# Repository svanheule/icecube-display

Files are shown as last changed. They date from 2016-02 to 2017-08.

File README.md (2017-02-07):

# IceCube LED display
This repository contains design documents and firmware source code for a number of LED displays
designed to show IceCube event data.

## Integration in Steamshovel
A Steamshovel artist was written using pyusb to enable remote rendering.
This allows people already familiar with the IceCube offline event viewer to also be quickly
able to get a new LED display up and running.

## Firmware
The display firmware is written using bare-metal C to provide close integration with the hardware.
Writing a new firmware implementation can take up quite some time, so try to re-use an existing
design if possible. All source code is contained in the `firmware` directory.

Source code documentation containing guidelines for new display and a short description of
existing displays can be compiled using Doxygen:
```{.sh}
$ doxygen Doxyfile
```

A copy of the documentation may be found at
http://icecube.wisc.edu/~svanheule/icecube-display.

Builds of the microcontroller firmwares can be found at
http://icecube.wisc.edu/~svanheule/images.
These builds can be used to upgrade existing devices, or provide a starting point for uploading
the device EEPROM when using a new device.

## Hardware
The `hardware` directory contains design documents for the displays.
This includes both mechanical documents for the display construction, as well as possible
PCB design documents.

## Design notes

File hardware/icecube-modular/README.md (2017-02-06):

This directory contains design files for the modular IceCube
display.

* `crates`: Dimensions of plywood pieces used to construct the different crates.
    All dimensions are expressed in centimeter, and were converted from a design
    with dimensions in inches.
    These designs assume a plate thickness of 12.7mm (0.5 inch), but the plate
    thickness used was 5.5mm, to reduce weight and costs. The pre-calculated
    dimensions were adapted as needed on the go, and the milled-out slots were
    replaced by -- easier to produce -- drilled out holes of similar diameter.
* `pcb`: KiCad design files for
  * `data_splitter`: PCB used to change from one 8P8C (RJ45) connection to 4
    4P4C connections, splitting the four pairs in an ethernet cables.
  * `string_adapter`: PCB used to insert power and data into the attachment
    points for the LED strips.
  * `libraries`: common footprints, etc.
* `strip_suspension_105mm.dxf`: Drawing for laser-cutting the PMMA strips used
  to suspend the LED strips.
* `strip_clip`: OpenSCAD design files for the clips that were put on the LED
  strips.
  The suspension strip can be inserted in the top clip, the bottom clip can
  be used to attach to a loop of elastid cord. This will put some tension
  on the strip, straightening it out.

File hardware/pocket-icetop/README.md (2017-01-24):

This directory contains the files used for fabrication of the table-top IceTop displays.

* `pocket_icetop.dxf`: drawing of the middle plate of the display. The top and bottom plate have
  the same outer dimensions, but lack cut-out that is used to feed cables through from the PCB
  to the LEDs. For use with strips of 60 LED/m.
* `pocket_icetop_large.dxf`: Same as the first drawing, except for use with strips of 30 LED/m.
* `pcb`: KiCad project with the design files for the display controller board.

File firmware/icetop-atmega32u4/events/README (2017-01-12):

The tabular data present in the .txt files in this directory contains the following columns:
    IceTop station number | Total charge | Mean pulse time (ns)

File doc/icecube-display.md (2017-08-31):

# Modular IceCube event display {#display_teensy_icecube}

The IceCube LED display built at UGent was based on the mechanical designs of the
UW River Falls displays, but uses the icecube-display firmware instead of
the Teensy's Arduino interface used in the original design.
It is a scale 1:500 display, so is approximately \f$(2m)^3\f$ in size,
and is driven by three Teensy 3.2 ARM microcontroller development boards.

## Display segmentation
The full IceCube detector was broken up into three display modules to facilitate transport,
each containing a Teensy board.
Provided there is a way to mechanically support the upper part of the module, each of the modules
can be controlled as an independent display that supports part of the IceCube detector.

* Front module: strings 1-30
* Center module: strings 31-50, optionally also contains the DeepCore strings (79-86)
* Back module: strings 51-78

\image html icecube-segment-layout/segment-assembly.png "Display segment assembly"

## Electrical
### Power and data distribution
A single module contains roughly one third of the IceCube strings.
At 60 DOMs per string, this equates to up to 1800 RGB LEDs that can draw 60mA at 5V
when set to full brightness.
Therefore two [5V-60A power supplies (HRP-300-5)](http://www.meanwell.com/productPdf.aspx?i=450)
are used in each module to power the LEDs.

To reduce the number of cables running to the fully assembled display, the front and back modules
can get their USB connection to the PC via the center module.
To achieve this, the center module contains a USB hub whose upstream port is accessible from the
side of the module.
Two downstream USB ports are provided facing the front and back modules.
A [multi-TT hub](http://plugable.com/products/usb2-hub-ag7/) was used to provide
optimal throughput on the high-speed USB connection leading to the hub.

All the electronics are located in the bottom part of the module.
The top part only contains a small amount of cabling to connect data lines of the LED strips
(see next section).

\image html icecube-segment-layout/segment-connections.png "Display segment connections"

The Teensy controllers use an 8-bit port to send serial data to 8 LED strips simultaneously.
To make these output pins easily accessible, the Teensys are seated in a
[OctoWS2811 adaptor](https://www.pjrc.com/store/octo28_adaptor.html).
The two RJ45 connectors are then each fed to a splitter board using CAT5e cables to provide 8 strip
ports.
Since 8 ports is smaller than the corresponding number of IceCube strings per display segment,
the data lines of up to four LED strips are connected in series, resulting in a strip with 60
to 240 LEDs.
The data lines for the first and third strip run from bottom to top, while the data lines for the
second and fourth strip run from top to bottom.
Connections between the strips are made inside the display segment boxes and do not change between
different assemblies of the display.
Each strip of 60 LEDs is powered through the bottom case and is equipped with a circuit breaker,
rated to 4A, to prevent one short circuit from taking down half the display segment.

\image html icecube-segment-layout/segment-cabling.png "Display segment strip cabling"

### LED strip layout configuration
The way the LED strips are grouped is not predetermined and depends on the length of the available
connecting cables, location of the microcontroller inside the module's bottom box, and of course
personal preferences of the person doing the cabling.
Therefore, the strip configuration is stored in \ref eeprom_layout "the microcontroller's EEPROM"
such that the same firmware can be used in different displays.
The below figure shows an example layout of the center module, with the corresponding JSON snippet
that can be used to generate the EEPROM data.

\image html icecube-segment-layout/segment-layout.png "Display segment strip layout"

The full JSON file may look as the example provided below. Note that not all display segments use
all 8 output ports, and not all ports have 4 strips connected in series.
If ports with less than 4 strips are present, the available ports should be populated starting with
the longest strips.
In the example below, the 'front' module's first seven ports have four strips,
and the last port only has two.
The 'center' and 'back' modules respectively have four and seven ports used for four strips,
and none on the last port(s).

\include display_config.json

A utility is provided (`firmware/icecube-teensy32/configurations/update_eeprom.py`) to generate and
upload the EEPROM data starting from this JSON file.
Note that after uploading a new configuration, the device should be power cycled for changes
to take effect.

## Firmware
### Development requirements
To build the firmware, `arm-none-eabi-gcc` is required.
It also uses the newlib C library implementation and a few headers provided by the
upstream Teensy repositories for compatibility with some `avr-libc` functionality.

### EEPROM usage
6 bytes of EEPROM are used to store the display specific properties.
The first and last supported string number denote a continous, inclusive range of IceCube strings
that can be displayed by the device.

Address offset | Description
--------------:|-------------
0x20 + 0x0     | Supported LED type: see ::display_led_type_t
0x20 + 0x1     | LED RGB order: see ::display_led_color_order_t
0x20 + 0x2     | First supported IceCube string number (in range 1-78)
0x20 + 0x3     | Last supported IceCube string number (in range 1-78)
0x20 + 0x4     | Support for DeepCore strings (boolean)
0x20 + 0x5     | Whether the first strip segment in each group is reversed (boolean)

Starting from offset 0x30, \f$4\times(1+8)\f$ bytes are used to store the LED strip mapping.
The first of each of these nine bytes indicates how many values
in the following 8-byte array are valid.
Although the number of valid strip segments is stored in the array, care should be taken that
mappings for non-existent LED strip segments don't go outside of the supported IceCube string count.
In case the firmware would want to read out these offsets anyway, it would re-use LED data
from other strings and be prevented from reading possibly invalid data.

The EEPROM segment below corresponds to the above center display segment.
The first LED strip on the second port maps to IceCube string \f$44=31+\text{D}_{16}\f$.
Note that the EEPROM segment is essentially a transpose of the table provided in the configuration
file segment.
The three last bytes (unused) of the segment mappings are shown here as '`00`', as per the
recommendation not to use non-existent buffer offsets.

<TABLE>
  <CAPTION>Display segment strip buffer offset map</CAPTION>
  <TR>
    <TH rowspan="2">Address offset</TH>
    <TH colspan="2">Data (hexadecimal)</TH>
  </TR>
  <TR>
    <TH>Ports used</TH>
    <TH>Buffer mapping</TH>
  </TR>
  <TR>
    <TD>0x30 +  0</TD><TD><TT>05</TT></TD><TD><TT>03 0D 04 06 10 00 00 00</TT></TD>
  </TR>
  <TR>
    <TD>0x30 +  9</TD><TD><TT>05</TT></TD><TD><TT>02 0C 0E 07 11 00 00 00</TT></TD>
  </TR>
  <TR>
    <TD>0x30 + 18</TD><TD><TT>05</TT></TD><TD><TT>01 0B 0F 08 12 00 00 00</TT></TD>
  </TR>
  <TR>
    <TD>0x30 + 27</TD><TD><TT>05</TT></TD><TD><TT>00 0A 05 09 13 00 00 00</TT></TD>
  </TR>
</TABLE>

Starting from 0x60, 16 bytes of EEPROM are used to store a group identifier. This enables
software to easily group controllers into a single, virtual display.
The length of this field is such that it can exactly store the binary representation of
an MD5 hash.
See ::DP_GROUP_ID for info on how to calculate this hash.

### Firmware flashing
To update the firmware on the Teensy, just press the program button.
`lsusb` should now show the Halfkay bootloader:

    $ lsusb | grep -e "Teensy"
    Bus 003 Device 102: ID 16c0:0478 Van Ooijen Technische Informatica Teensy Halfkay Bootloader

The new firmware can now be uploaded via `make upload` when building from source, or using the
`teensy_loader_cli` utility when programming a compatible .hex file:

    # Only one device can be programmed at a time
    teensy_loader_cli --mcu=mk20dx256 -w icecube_display.hex

### Initial programming
When a new Teensy is used to run this firmware, or the Teensy has been used for other applications
before, the EEPROM will not yet be properly initialised.
After programming the device firmware, the `upload_eeprom` target can be used to upload the
device's EEPROM file.
After a reset, the device will now be able to read out sensible EEPROM values and be ready for use.

## Cost estimate
The prices list below do not include VAT.
Total estimate (without labor costs) for the UGent display is ~€3000.
The UW River Falls cost estimate was $4000, mainly due to more expensive LED strips.

  * Custom PCBs (EuroCircuits): €300
  * Electronics (Mouser, Farnell): €1200
    * Cables: 4 core, 6 core, 2 core (0.88mm²/18AWG)
    * Connectors: 4P4C, 6P6C, terminal blocks, a few case mount USB plugs
    * Power supplies
    * Teensys
  * LED strips: €750 + €150 import customs (shipping from China)
    * 32× 5m WS2812B
    * Silicone sleeving, endcaps
  * Plywood 5.5mm × (2500mm × 1220mm (?)): cost unknown.
    UW-River Falls states $400 (8 sheets 5mm, 4 sheets 12mm inch)
  * Black backdrop curtain: €70

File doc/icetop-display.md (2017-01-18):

# Table-top IceTop display {#display_atmega32u4_icetop}

The table-top IceTop event display developed at UGent was the origin of this firmware project.
It is a portable display that uses strips with 30 or 60 LED modules per meter, resulting in
acceptable dimensions that facilitate it being caried around and used e.g. for classes on
astroparticle physics.
It is driven by a self-designed display controller, built around the ATmega32U4 microcontroller.

Due to the fine pitch of the 60 LED/m strips, the in-fill stations have not been included in the
small verison of the display.
They can be included if the display uses a 30 LED/m pitch, and the firmware is able to
deal with these different configurations.

The LED strips contain APA-102C devices which were
selected due to their adjustable brightness setting and clocked data input
lines. This results in less stringent timing contraints for the controlling
electronics, as the controller can decide how fast the data is clocked, and
clock jitter is less of an issue.

## Display usage
The display has a number of input buttons and LEDs to interact with and relay status information to
the user.
The green *Power* LED indicates whether the display is receiving 5V power input.
The orange *USB activity* LED will light up when there is a USB connection, and blink when there
is bus activity, e.g. when display data is transmitted.
Aside from Steamshovel connectivity, this display also supports stand-alone operation.

\image html front.png "Side view of the LED display"

### Stand-alone operation
In stand-alone mode, when the display is not connected via USB and only powered on, the display can
also show a number of IceTop events stored on the device itself.
For every event, first a time-lapse will be shown, followed by an overview.
The light intensity of the LEDs is related to the amount of light collected by the corresponding
IceTop station, and the colour is related to the time when this light was collected.
Red means early in the event, blue means late.
After pressing either of the blue buttons, the display will start cycling through the 9 stored
IceTop events.
At any point, you can go to the next event using the *Forward* button. You can also pause an event
overview by pressing *Play/Pause* during playback, or resume playback by pressing the button again
when the display is paused.

First, three down-going events of increasing energy will be shown.
Then come three slightly inclined events, and three events with large inclination, again each group
with increasing energy.
As the energy of the events increases, you will see that the part of the detector that is activated
by the airshower also increases.
Also, as the inclination of the showers increase, it becomes clear that the shower is actually
contained in a moving surface when it hits the detector.
Downgoing events activate the detector almost simultaneously, while inclined events seem move along
the surface of the detector.

## Firmware
### Development requirements
Building the firmware can only be done with `avr-gcc`.
The firmware also uses `avr-libc` to provide a C implementation of low-level microcontroller
features.

### EEPROM details
Three bytes of the LED information EEPROM are used to store display specific information:

Address offset | Description
--------------:|-------------
0x20 + 0x0     | LED count: 78 for the small display, 81 for the large display
0x20 + 0x1     | Supported LED type: see ::display_led_type_t
0x20 + 0x2     | LED RGB order: see ::display_led_color_order_t

Although currently stored in the firmware image, the LED mapping could be moved to the EEPROM
for future displays.
In this case up to 81 additional bytes of EEPROM can be used, starting from address 0x30.

### USB firmware upgrade
The recommend way to upgrade the device firmware is via USB.
To perform the upgrade, first power the device using the 5V power supply, and connect the
display to the computer used to perform the upgrade via a USB cable. You should see the green
and orange LED light up.
The display now needs to be rebooted into firmware upgrade mode.
To do this, press and hold the *Forward* button while pressing the *reset* button.
After releasing *reset*, the *Forward* button can also be released and the display should now be in
firmware upgrade mode. The green LED will still be on, but the orange LED will now be off.

When performing the `lsusb` command on Linux, you will now see the Atmel bootloader
showing up in the listing:

    $ lsusb | grep -e "Atmel"
    Bus 001 Device 039: ID 03eb:2ff4 Atmel Corp. atmega32u4 DFU bootloader

After building the firmware from source, the new firmware can be uploaded using a custom make
target:

    make upload

If the firmware was provided as a pre-compiled binary file (e.g. as `icetop_display.hex`), you can
upload the firmware using the `avrdude` command:

    # When only one device is connected
    avrdude -p ATMEGA32U4 -c flip1 -U flash:w:icetop_display.hex

    # When multiple devices are connected (and ready to be programmed),
    # you should also specify which port number to use (use lsusb to find out)
    avrdude -p ATMEGA32U4 -c flip1 -P usb:001:039 -U flash:w:icetop_display.hex

### ICSP firmware upgrade
The device can also be programmed using the ICSP header on the board.
Note that any normal firmware upgrade can be performed via USB, so using the ICSP port is not
the recommended way of upgrading your display!
To access the ICSP header, the bottom plate of the device needs to be removed.
Pin 1 of the header is marked with a slightly offset angle, and is next to the `P3` marking.
The VCC line of the ICSP header can be used to power the device, so make sure that the
programmer's VCC line is either disconnected, or that the external power suppy is not used!

With an ICSP programmer, the flash and EEPROM will be erased prior to the device upgrade.
It is recommended to configure the CMake system to generate the right EEPROM data and program
the fuses and lock bits, the EEPROM, the program flash, and the bootloader flash.
When performing the initial flash of the device after assembly, a complete chip erase should be
performed beforehand to ensure the lock bits are reset and a new firmware can be flashed to the
device.

## Cost estimate
*Total:* €110 (excl. VAT)
  * 78 APA-102C LEDs (60 LEDs/m strips): €27 (€21/m)
  * 5V, 5A power supply (HNP40EU-050/HNP36-050): €15
  * Custom PCB: €15 (ordered 5pc. at [eurocircuits](http://eurocircuits.com))
  * Electronic components: €20
  * Laser cut PMMA (3 plates): €30

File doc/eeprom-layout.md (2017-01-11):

# EEPROM layout {#eeprom_layout}

The display's microcontroller uses its available EEPROM to store some display-specific details
such as the serial number, the number and type of LEDs, etc.
The following table provides an overview of the EEPROM sections currently defined and used by
the display controller firmwares.
The EEPROM sections are all put in a specific code section. Linker flags or a custom linker script
should be used in order to ensure these sections end up in the EEPROM.

Description              | Address offset  | Length             | Code section
-------------------------|----------------:|-------------------:|-------------
Serial number            | 0x000           | 32                 | .serialno
Display LED information  | 0x020           | varies; at most 16 | .displayprop
Display LED map          | 0x030           | varies             | .portmap

Firmwares are allowed to use the reserved EEPROM segments for LED information and LED mapping
as they see suit, provided they stick to the reserved space.
Please refer to the different implementation pages from the \ref display_implementations
"list of existing implementations".

\par Serial number
The serial number is stored as a null-terminated UTF16-LE string, as required by the USB
specification.
The 32 bytes of reserved EEPROM can therefore be used to store 15 characters.
See \ref display_serialno on which format to use for the serial number string.
```{.c}
// Assuming the platform is little-endian
const char16_t USB_STRING_SERIALNO[] __attribute__((section(".serialno")) = u"ICD-IC-000-0000";
```

\par Display LED information
Reserved to store 16 bytes of information on the LED type, RGB color order, LED count...

\par Display LED map
Since the electrical connections between the LEDs is very likely to be different from the
sequential string numbers, space is reserved to store a mapping of buffer offsets to the
physical layout of LEDs.

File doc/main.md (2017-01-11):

# Event data LED display {#mainpage}

The IceCube Neutrino Observatory is a high energy neutrino and cosmic ray detector located at the
Amundsen-Scott South Pole Station.
Its main components -- IceCube and DeepCore in the deep-ice, and IceTop at the glacier's surface --
consist of thousands of Digital Optical Modules or DOMs that detect Cherenkov light emitted by
particles travelling through the ice.
To be able to represent the information about the captured light, a number of LED displays have
been developed over time.
These displays use an (RGB) LED to represent a single DOM or a cluster of DOMs.
Detection time is usually mapped to color, and the amount of light detected is mapped to brightness.
This documentation accompanies the firmware that was originally written to drive the displays built
at Ghent University, and serves to provide details on how to implement new displays in the same
framework.

## Display electronics and firmware
To simplify the LED driving, the displays use RGB LED packages that include a driver and serial
communications such as the WS2812B or APA102.
These are then driven in turn by a microcontroller that also sports a USB port to provide
connectivity to a PC.
By allowing the PC to send frames of raw RGB LED data, these displays are essentially a generic
video display, albeit one arranged in a rather odd layout that matches the IceCube detector.

To start designing your own display (firmware), the following resources can be usefull:
* Check the \subpage display_implementations "list of implementations" to see if anything
  already exists that fits your needs, or can be adapted to do so.
* Otherwise, read the \subpage new_implementations "guidelines for new implementation".

## USB connectivity and steamshovel
The device's USB port can be used to transfer display data from a USB host. A detailed overiew
can be found in the \ref usb_communication "firmware documentation".
A Steamshovel artist has been implemented using this connectivity to be able to display
any simulation or data file.

The options of the LedDisplay artist have been modelled after the Bubbles artist:
  * *Device*: select one of the detected LED displays. Detection happens once at start-up.
  * *Static color* and *brightness*: Select a color and brightness for static DOM maps.
  * *Compression*: Exponent of the power law used to compress hit info. Since a linear scale would
      hide the details in low charges, the high charges are compressed, giving the display a larger
      dynamic range. Note that display gamma correction is performed independently of this setting.
  * *Colormap*: time to color mapping.
  * *Finite pulses*: If 'Use infinite pulses' is checked, a hit will be shown starting from its time
      of detection. Otherwise it will disappear after the selected duration. This is different from
      the Bubbles setting in that the highest value of the pulse duration slider isn't interpreted
      as positive infinity, but just \f$10^5\f$ns.

\image html screenshot-steamshovel.png "Steamshovel with LedDisplay artist"

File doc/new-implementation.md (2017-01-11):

# Guidelines for new implementations {#new_implementations}

Using the C programming language, the icecube-display firmware project was developed with multiple
hardware implementations in mind.
A number of the core firmware modules have a generic implementation, to enable re-use on different
platforms.
For the firmware modules that are too closely tied to the hardware itself, only a header file
is provided to provide the common interface that other modules build on.

## CMake
The current firmware implementations are all designed as CMake projects.
This provides convenient out-of-source builds and provides a single interface to build and upload
firmware images:

* `make`: Compiles the firmware image.
* `make upload`: Uploads the firmware image to the device, when the device is in programming mode.

## Firmware structure
### Device initialisation
Since the firmware uses bare-metal C, microcontroller hardware initalisation has to be performed
by the user, and a memory pool for display frames should be allocated before
starting to generate and write display data.
Display firmwares should call the following initialisation routines in the listed order to prevent
firmware malfunction.

1. \ref init_display_properties() \n
  Initialises the display properties from the EEPROM data.
  Since this information is platform specific, no common implementation is provided.
2. \ref init_frame_buffers() \n
  Allocates the frame buffer memory pool. Called early to reduce chances of heap fragmentation.
  This function relies on the information initialised by init_display_properties().
3. \ref init_display_driver() \n
  Initialises the hardware required to drive the LEDs.
  Hardware dependent, so must be implemented separately for every display type.
4. \ref init_remote() \n
  Initialises the remote communications hardware and firmware.
  Strictly spoken not required if you don't want remote connectivity.
  Implementing \ref remote.h for the USB communications requires a good understanding of the
  underlying hardware. If possible, try to stick to an existing platform to avoid having to write
  the code to \ref usb_endpoint_control "drive the EP0 state machine" and properly manage the
  \ref usb_device "USB device".
5. \ref init_frame_timer() \n
  Starts the frame timer to enable periodic clearing of the frame FIFO.
  Requires a \ref frame_timer_backend.h "frame timer backend" implementation.

### Hardware dependent features
The following files are part of the base display functionality, but are hardware specific.
An implementation should be provided by every new firmware:
* \ref display_driver.h
* \ref frame_timer_backend.h
* \ref display_properties.h
* \ref remote.h
* \ref usb/led.h
* \ref usb/address.h
* \ref usb/endpoint.h

A common implementation for \ref usb/descriptor.h is available, but may use different
constants per platform. This is provided as a CMake configurable file:
* usb/descriptor.c.in

Of course other firmware modules can be provided to extend this base functionality.
See \ref display_atmega32u4_icetop "firmware/icetop_atmega32u4" for an example with
stand-alone operation as an additional feature.

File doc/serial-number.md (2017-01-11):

# Serial number {#display_serialno}

The display serial number is a 15 character string with "ICD-zz-yyy-xxxx" as format:
* __zz__: 'IT' or 'IC', depending on whether the device is meant to display IceTop or IceCube data.
* __yyy__: Sequential number indicating the display model. All displays with the same zz-yyy value
    should be able to use the same device firmware.
* __xxxx__: Sequential number to provide a unique identifier for the hardware.

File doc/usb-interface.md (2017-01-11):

# USB communication {#usb_communication}

The LED display is equipped with a USB port to provide the possibility of using a PC
to display IceCube event data not embedded in the device's firmware,
or make use of nicer effects that aren't so easy to produce using only the microcontroller.
A full-speed USB 2.0 compliant interface is provided, using `0x1CE3` as a vendor ID.
The vendor ID is *not* registered with the [USB-IF](http://usb.org), as this would be
[rather expensive](http://www.usb.org/developers/vendor/) for a small scale project like this.

The full-speed interface provides a bandwidth of 12Mbps, enough to run thousands of LEDs at 25 FPS.
The display interface is provided in a very generic fashion, so any application that can
render (low resolution) RGB data at video frame rates, can show this on the display.

## USB device details
The interface presented by the device consists of two endpoints:
* EP0: default control endpoint for status reporting and control
  * \subpage usb_endpoint_control
  * \subpage display_metadata
* EP1: bulk endpoint for frame data transfer to the device
  * \subpage usb_remote_renderer

After enumeration is completed, the device can be used by the user.
Unless it is known beforehand which device will be present, the display has to be queried to check
which LED type it supports, how many LEDs are present, and what kind of data that can be displayed.
Querying the display is achieved by obtaining a \ref display_metadata "display metadata report".
Once the buffer structure and content is determined based on the display properties, a display
frame buffer can be filled with appropriate data and transmitted to the display. This is achieved
by sending the buffer data to the \ref usb_remote_renderer "bulk endpoint".

## Multi-segment display facilities
It is possible to construct a single large display, e.g. to represent IceCube, consisting of
multiple segments each driven by its own microcontroller.
Since every microcontroller represents a single USB device, these actually behave as independent
displays.
When displaying fast moving images on these composite displays however, care has to be taken to
prevent tearing.
This occurs when one segment is displaying frame data ahead of an adjacent segment,
possilby resulting in visible discontinuities.
To prevent tearing, different segments should display data from the same frame as close together in
time as possible.
Some initial synchronisation mechanism has been provided, described in \subpage led_display_sync.

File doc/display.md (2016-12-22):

IceTop LED event display {#mainpage}
========================

## The IceTop detector ##

The surface detector of the IceCube neutrino observatory is better known as the IceTop detector.
It's purpose is to detect and measure extensive airshowers produced by highly energetic particles
colliding with the earth's atmosphere at the South Pole, by measuring the Cherenkov light the
particles in the air shower produce when they cross the detector.

The IceTop detector consists of 81 stations, each consisting of two tanks.
Each tank has two photosensitive detection devices called DOMs or Digital Optical Modules.
One of these DOMs is configured to detect small signals, the other to correctly detect the large
which would saturate the first DOM.
Of the 81 stations, the 3 in-fill stations are placed in the middle to create a more densely
instrumented region of the detector, allowing it to detect air showers of lower energy.

The picture below shows the geometry of the detector, as well as the 3 in-fill stations in gray.
The LED display mimics this geometry, by putting each station on a regular hexagonal grid, instead
of the slightly irregular grid of the actual detector.
The in-fill stations have not been included in the small display due to a lack of space for the LEDs.

\image html icetop-array.png "IceTop detector array layout"
\image latex icetop-array.pdf "IceTop detector array layout" width=0.7\textwidth

## Display usage ##

The display has a number of input buttons and LEDs to interact with and relay status information to
the user.
The green *Power* LED indicates whether the display is receiving 5V power input.
The orange *USB activity* LED will light up when there is a USB connection, and blink when there
is bus activity, e.g. when display data is transmitted.

\image html front.png "Side view of the LED display"
\image latex front.pdf "Side view of the LED display" width=0.9\textwidth

### Stand-alone operation ###
In stand-alone mode, when the display is not connected via USB and only powered on, the display can
also show a number of IceTop events stored on the device itself.
For every event, first a time-lapse will be shown, followed by an overview.
The light intensity of the LEDs is related to the amount of light collected by the corresponding
IceTop station, and the colour is related to the time when this light was collected.
Red means early in the event, blue means late.
After pressing either of the blue buttons, the display will start cycling through the 9 stored
IceTop events.
At any point, you can go to the next event using the *Forward* button. You can also pause an event
overview by pressing *Play/Pause* during playback, or resume playback by pressing the button again
when the display is paused.

First, three down-going events of increasing energy will be shown.
Then come three slightly inclined events, and three events with large inclination, again each group
with increasing energy.
As the energy of the events increases, you will see that the part of the detector that is activated
by the airshower also increases.
Also, as the inclination of the showers increase, it becomes clear that the shower is actually
contained in a moving surface when it hits the detector.
Downgoing events activate the detector almost simultaneously, while inclined events seem move along
the surface of the detector.

### USB connectivity and steamshovel ###

The device's USB port can be used to transfer display data from a USB host. A detailed overiew
can be found in the [firmware documentation](\ref usb_endpoint). A Steamshovel artist has been
implemented using this connectivity to be able to display any simulation or data file.

The options of the LedDisplay artist have been modelled after the Bubbles artist:
  * *Device*: select one of the detected LED displays. Detection happens once at start-up.
  * *Static color* and *brightness*: Select a color and brightness for static DOM maps.
  * *Compression*: Exponent of the power law used to compress hit info. Since a linear scale would
      hide the details in low charges, the high charges are compressed, giving the display a larger
      dynamic range. Note that display gamma correction is performed independently of this setting.
  * *Colormap*: time to color mapping.
  * *Finite pulses*: If 'Use infinite pulses' is checked, a hit will be shown starting from its time
      of detection. Otherwise it will disappear after the selected duration. This is different from
      the Bubbles setting in that the highest value of the pulse duration slider isn't interpreted
      as positive infinity, but just \f$10^5\f$ns.

\image html screenshot-steamshovel.png "Steamshovel with LedDisplay artist"
\image latex screenshot-steamshovel.png "Steamshovel with LedDisplay artist" width=0.7\textwidth

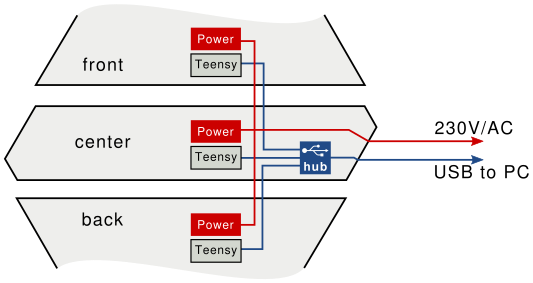
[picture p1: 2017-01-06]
doc/icecube-segment-layout/segment-connections.png

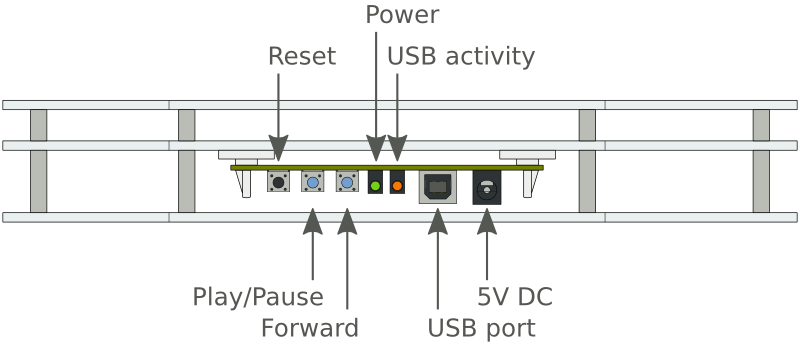
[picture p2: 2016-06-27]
doc/front.png

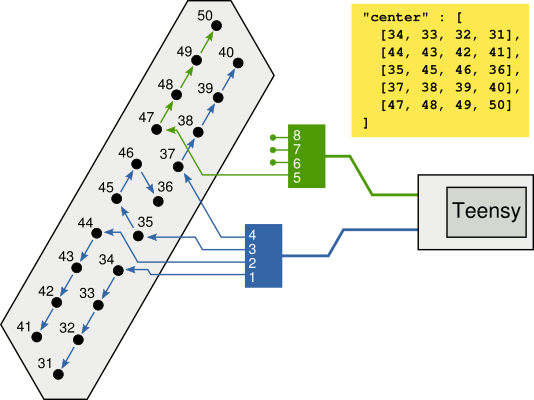
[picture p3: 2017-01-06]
doc/icecube-segment-layout/segment-layout.png

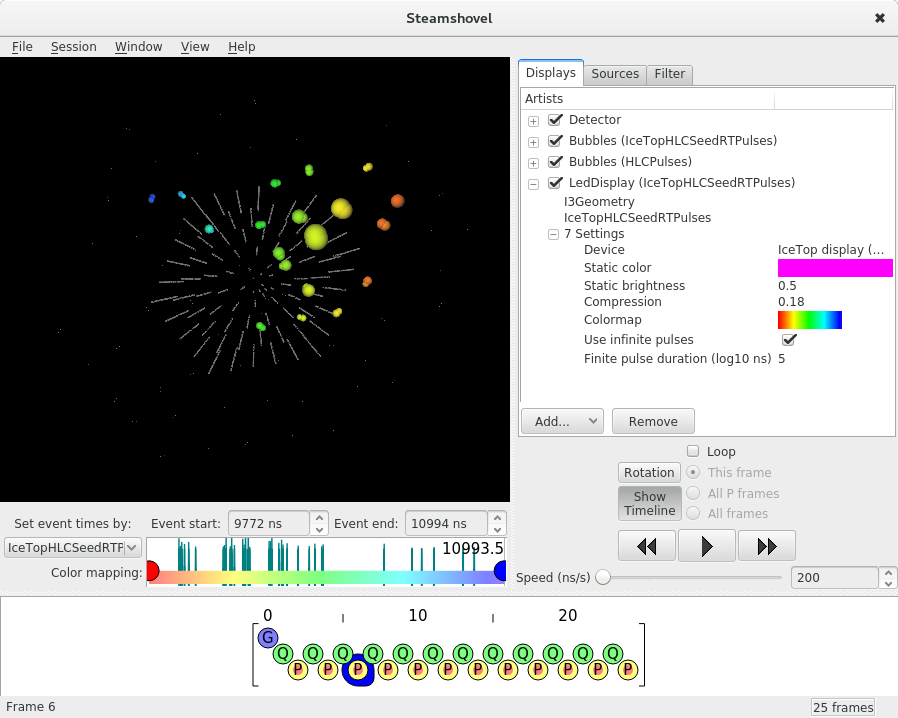
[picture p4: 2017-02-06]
doc/screenshot-steamshovel.png

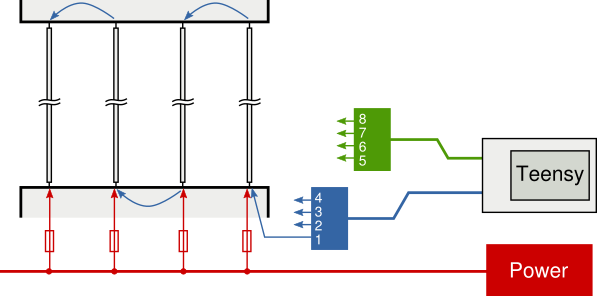
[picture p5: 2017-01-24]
doc/icecube-segment-layout/segment-cabling.png

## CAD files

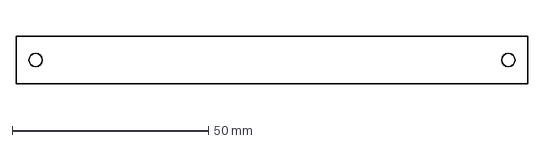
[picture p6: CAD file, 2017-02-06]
hardware/icecube-modular/strip_suspension_105mm.dxf
130.5 x 12.0 mm

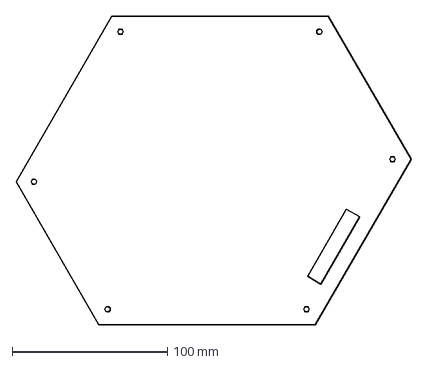
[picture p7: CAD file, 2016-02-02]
hardware/pocket-icetop/pocket_icetop.dxf
254.3 x 198.7 mm

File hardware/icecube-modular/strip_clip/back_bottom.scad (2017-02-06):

include <clamp_common.scad>;


module back_bottom() {

translate(v=[-base_width/2, -base_length/2, 0]) {
	cube(size=base_size);
}

module pin() {
	pin_height = base_thickness - 0.6; // 0.6mm spacing/tolerance
	pin_radius = pin_radius_base; // 3mm hole
	cylinder($fn=8, h=pin_height, r=pin_radius);
}


module left_pin() {
	translate(v=[-base_width/2+pad_width/2, 0, base_thickness]) {pin();}
}

left_pin();
mirror(v=[1,0,0]) {
	left_pin();
}

}

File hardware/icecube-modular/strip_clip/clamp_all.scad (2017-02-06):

include <front.scad>;
include <back_bottom.scad>;
include <back_top.scad>;

split = 3;

translate(v=[(base_width+split)/2, (base_length+split)/2, 0]) {front();}
translate(v=[-(base_width+split)/2, (base_length+split)/2, 0]) {front();}
translate(v=[(base_width+split)/2, -(base_length+split)/2, 0]) {back_top();}
translate(v=[-(base_width+split)/2, -(base_length+split)/2, 0]) {back_bottom();}

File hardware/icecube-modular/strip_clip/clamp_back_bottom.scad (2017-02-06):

include <back_bottom.scad>;

back_bottom();

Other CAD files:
hardware/pocket-icetop/pocket_icetop_large.dxf
hardware/icecube-modular/strip_clip/back_top.scad
hardware/icecube-modular/strip_clip/clamp_back_top.scad
hardware/icecube-modular/strip_clip/clamp_common.scad
hardware/icecube-modular/strip_clip/clamp_front.scad
hardware/icecube-modular/strip_clip/front.scad

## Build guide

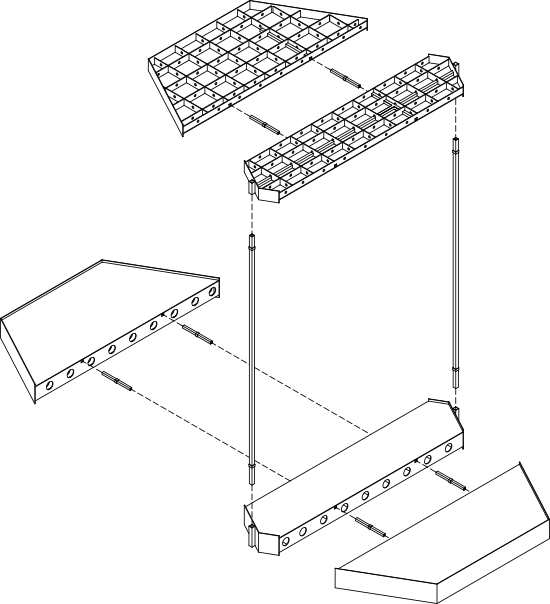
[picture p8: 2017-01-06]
doc/icecube-segment-layout/segment-assembly.png

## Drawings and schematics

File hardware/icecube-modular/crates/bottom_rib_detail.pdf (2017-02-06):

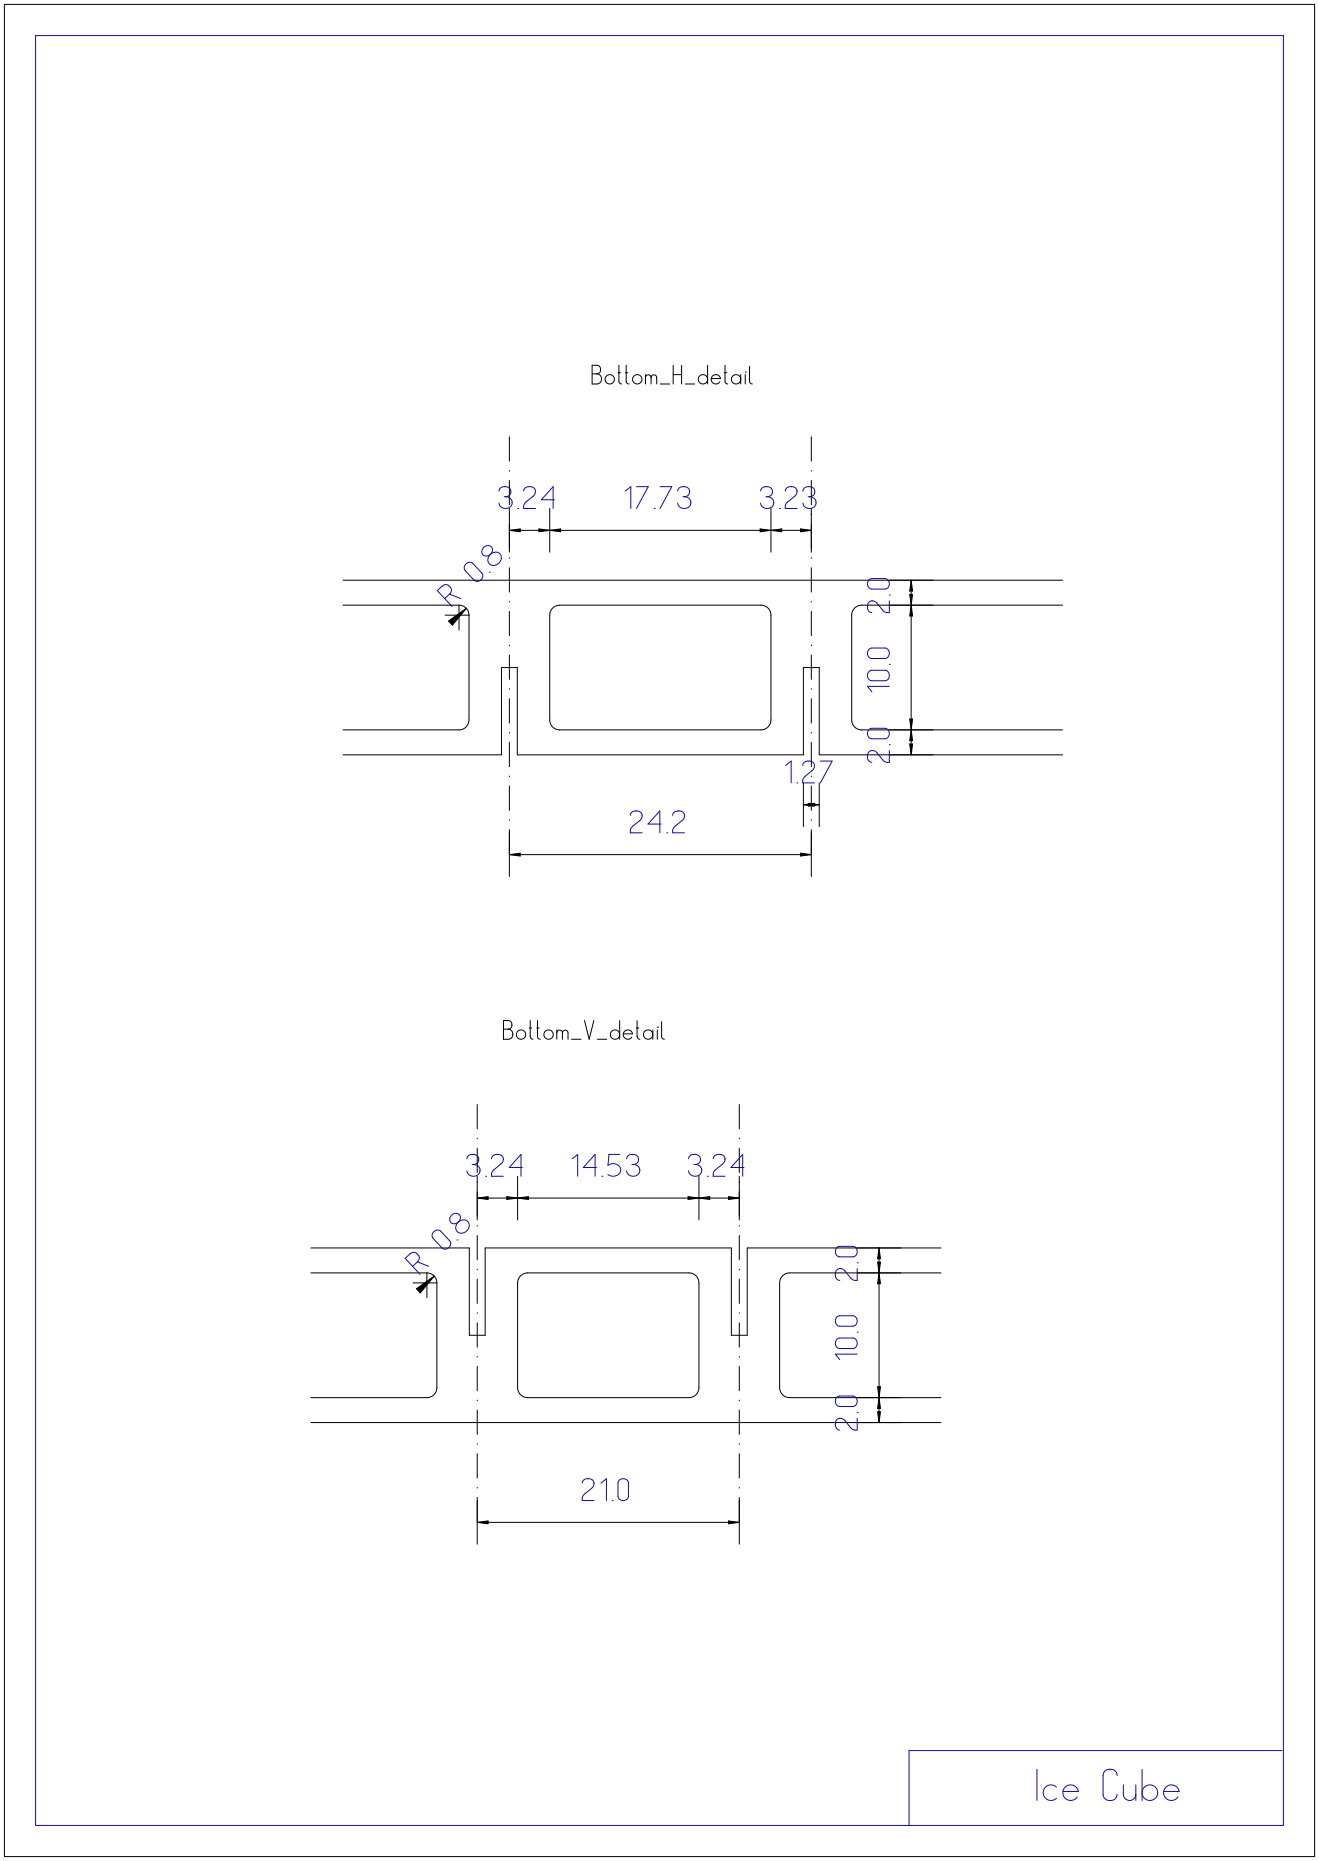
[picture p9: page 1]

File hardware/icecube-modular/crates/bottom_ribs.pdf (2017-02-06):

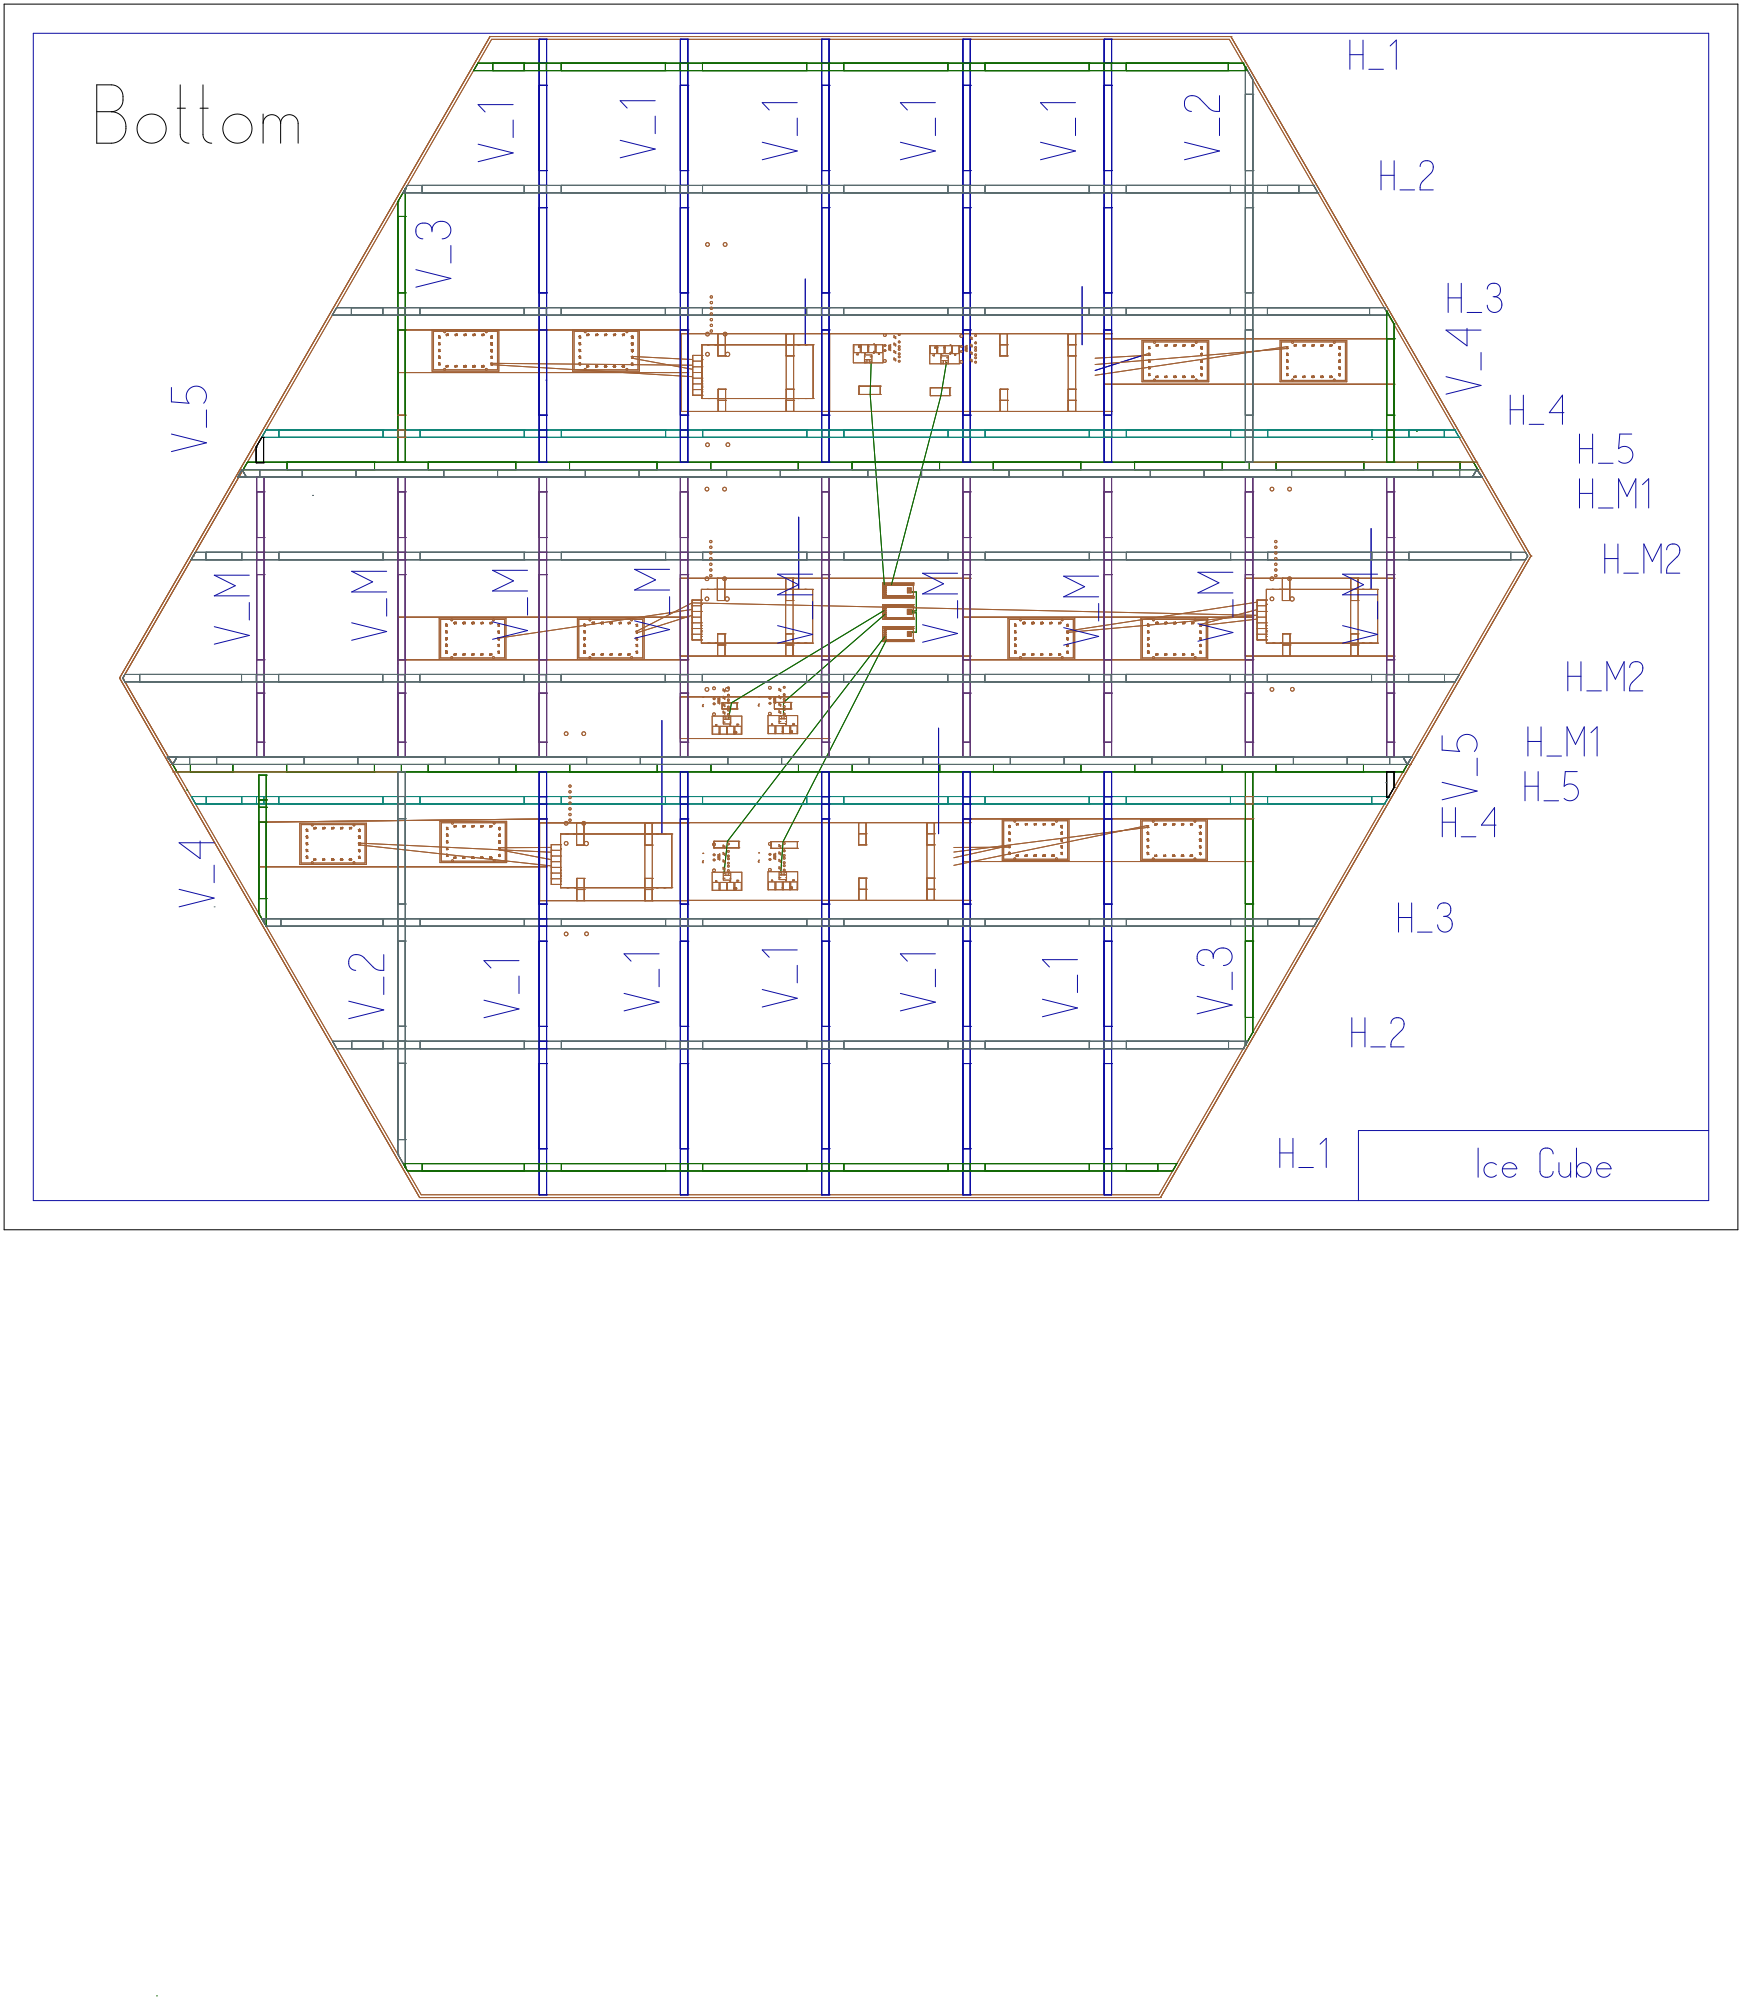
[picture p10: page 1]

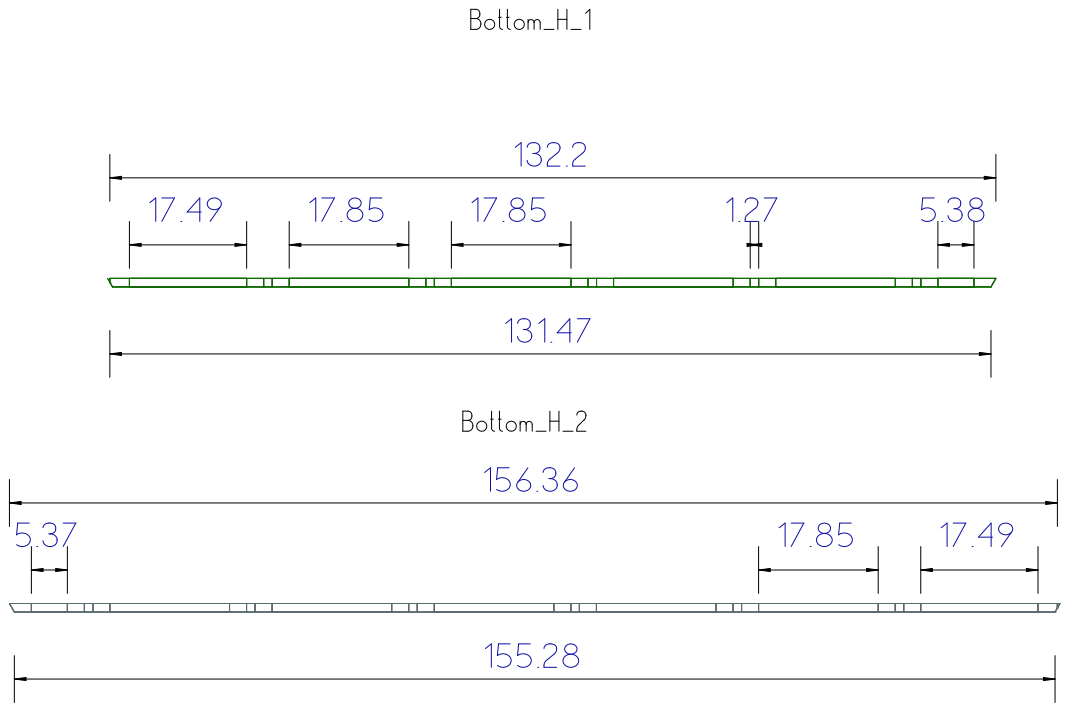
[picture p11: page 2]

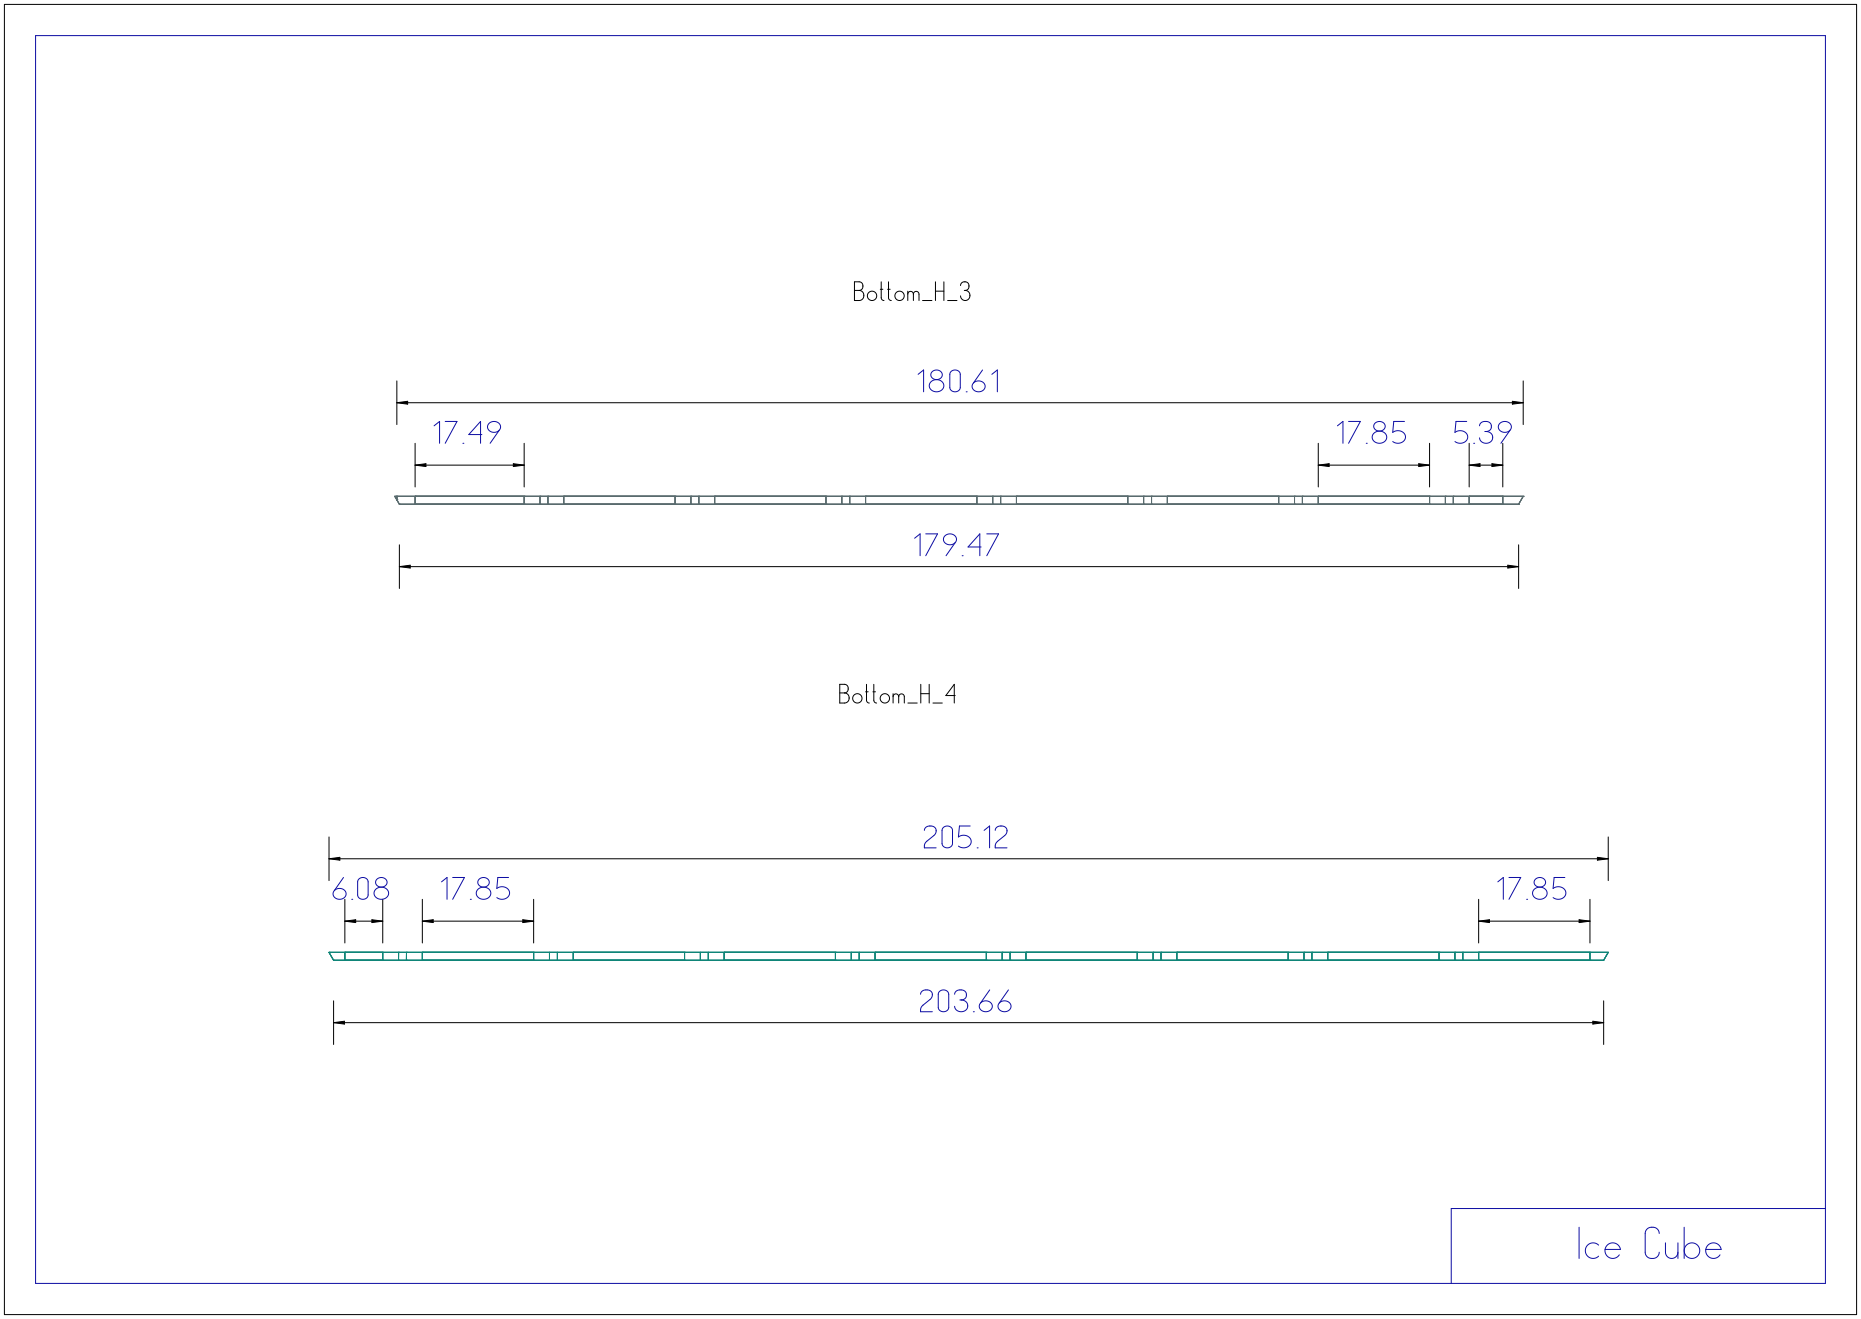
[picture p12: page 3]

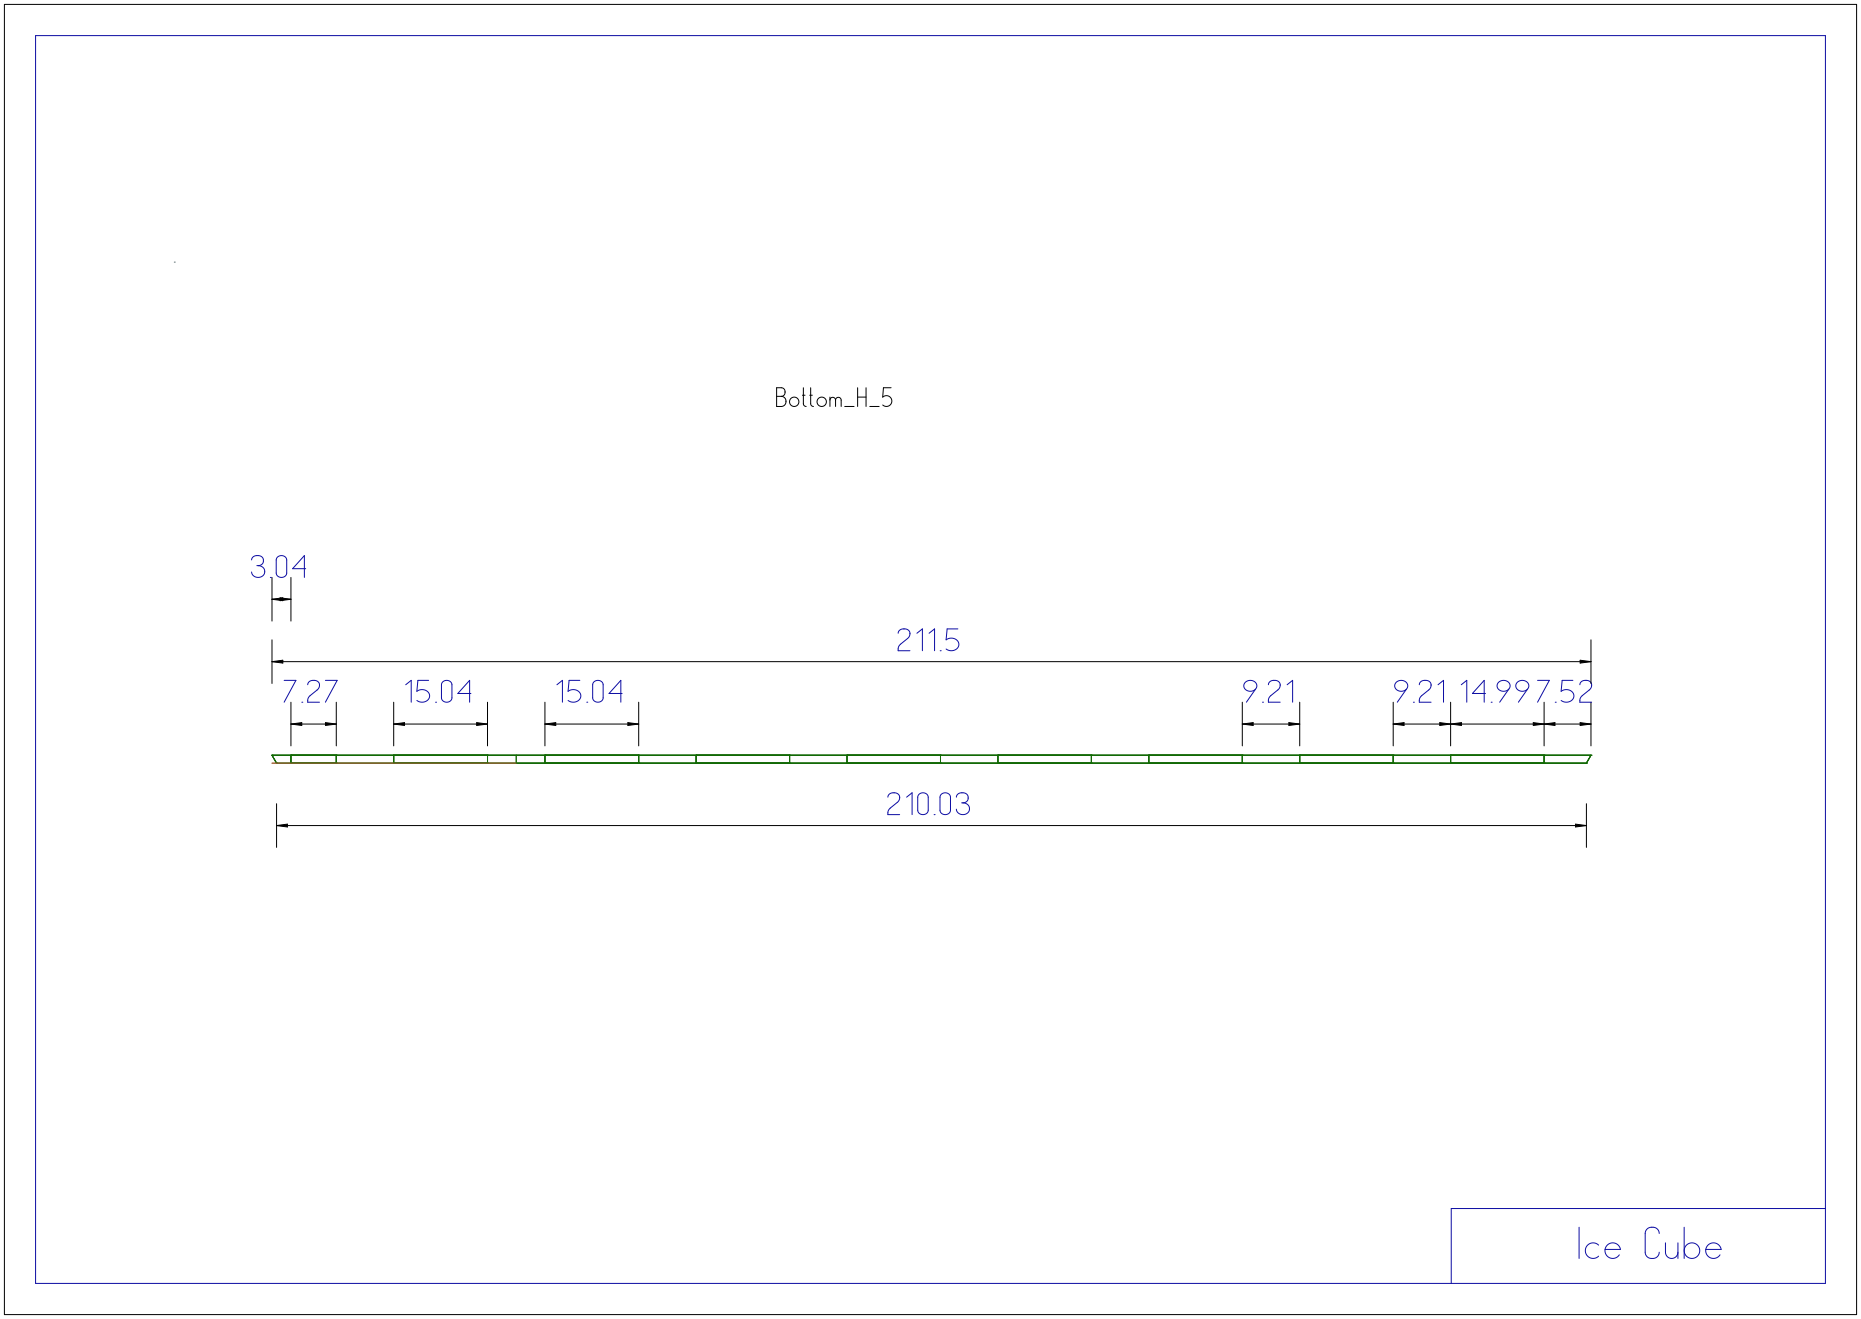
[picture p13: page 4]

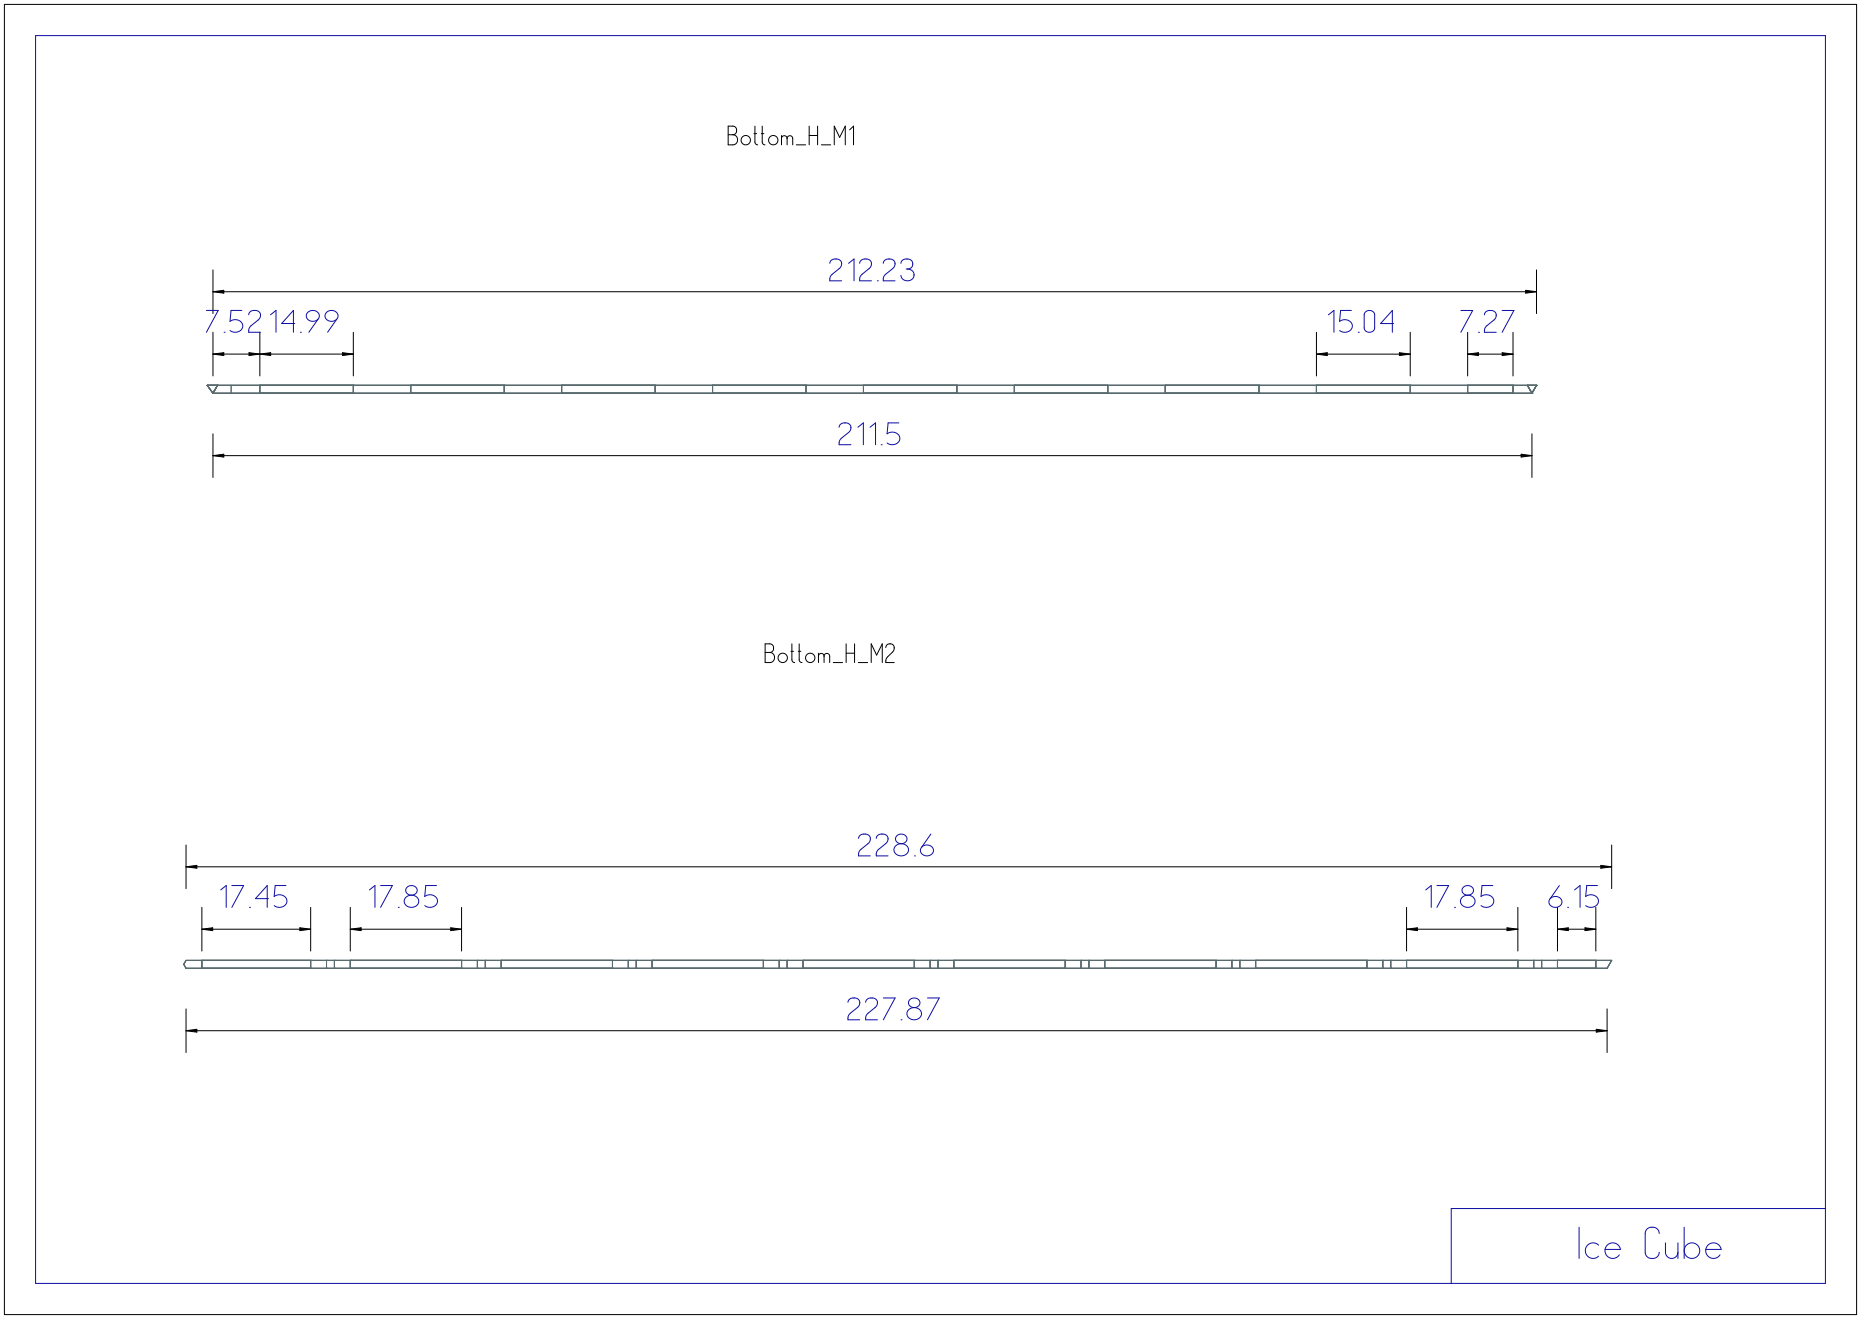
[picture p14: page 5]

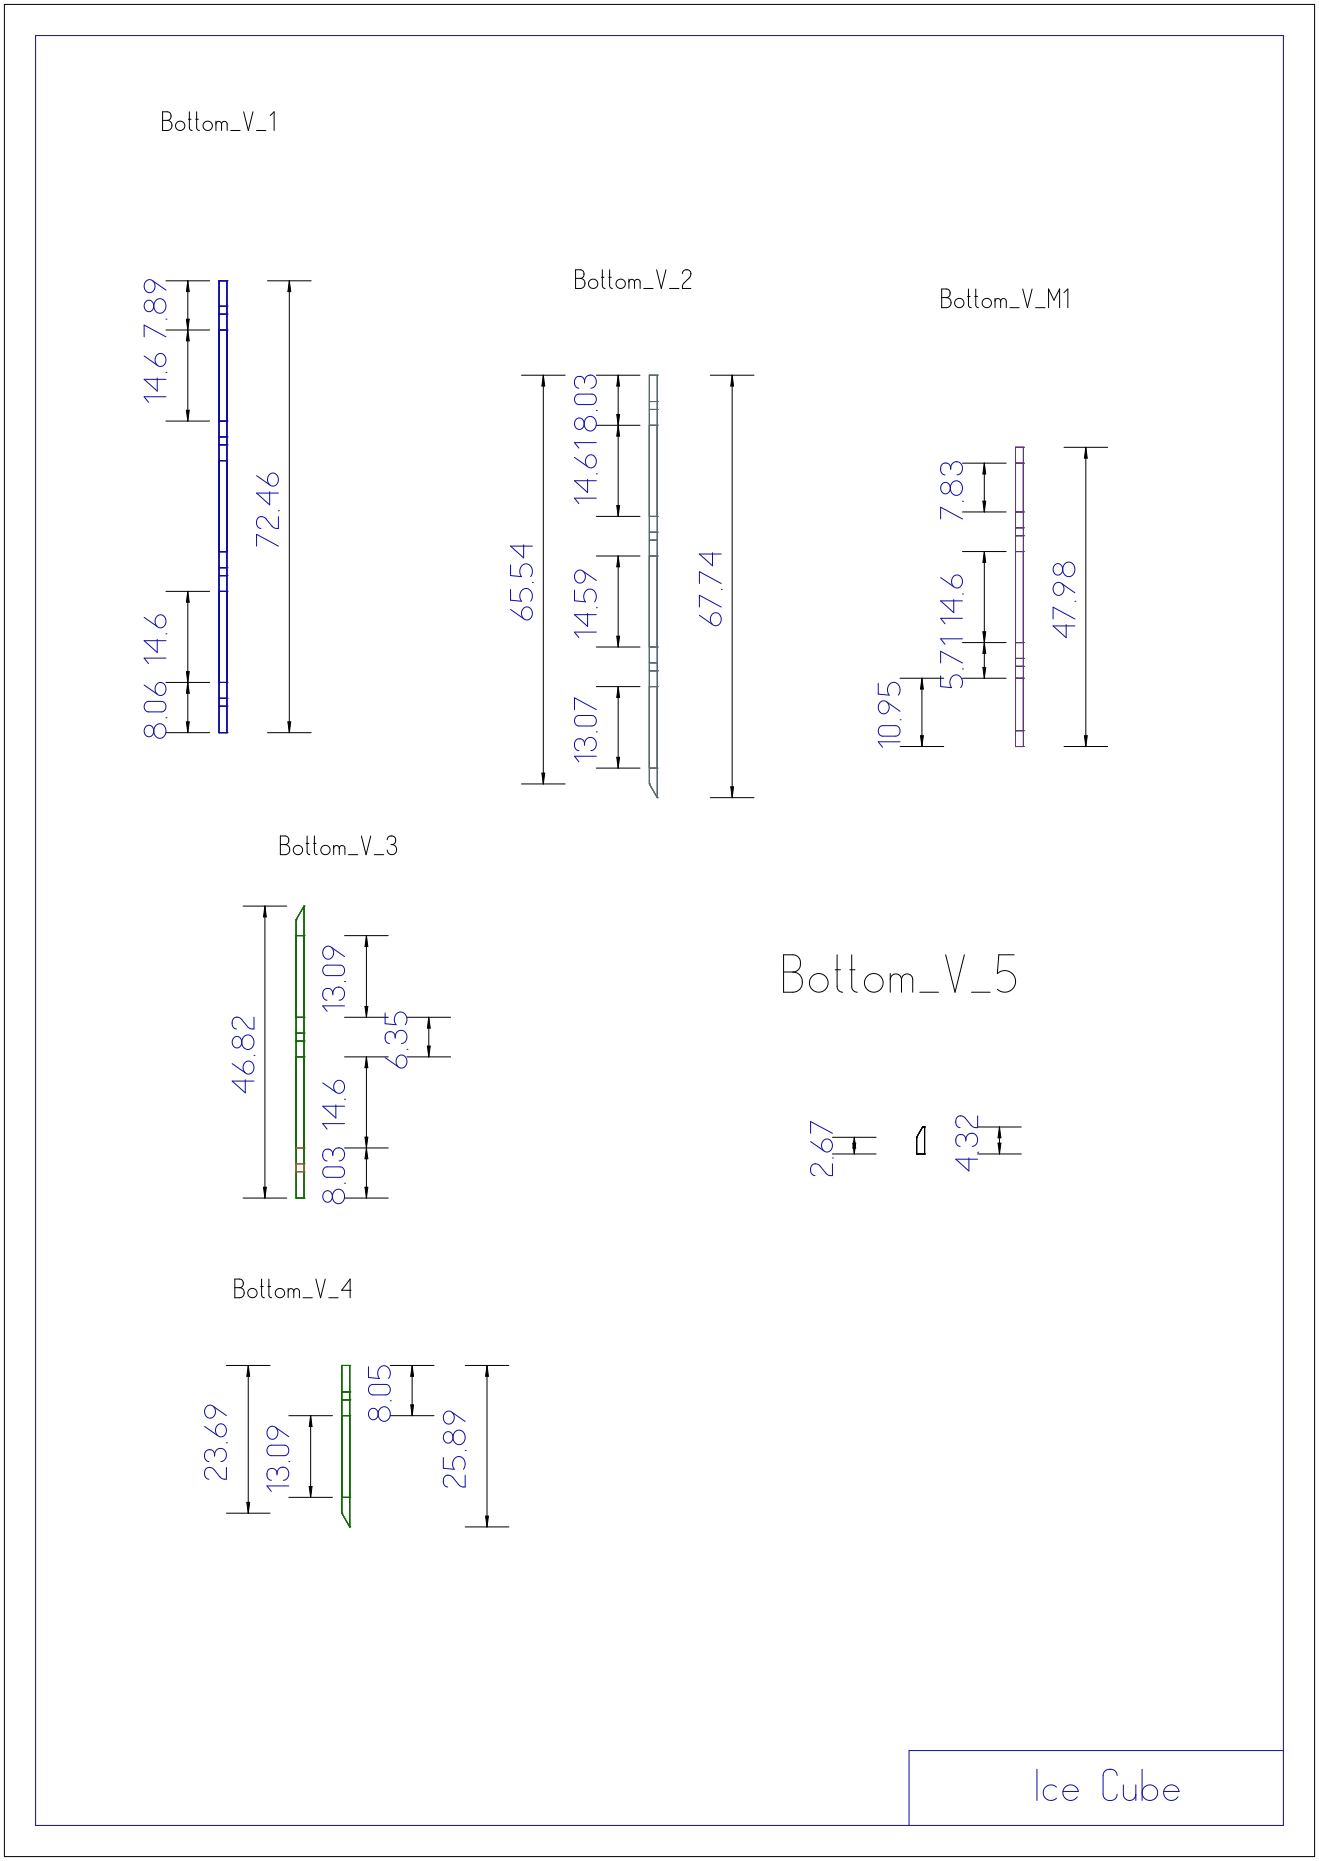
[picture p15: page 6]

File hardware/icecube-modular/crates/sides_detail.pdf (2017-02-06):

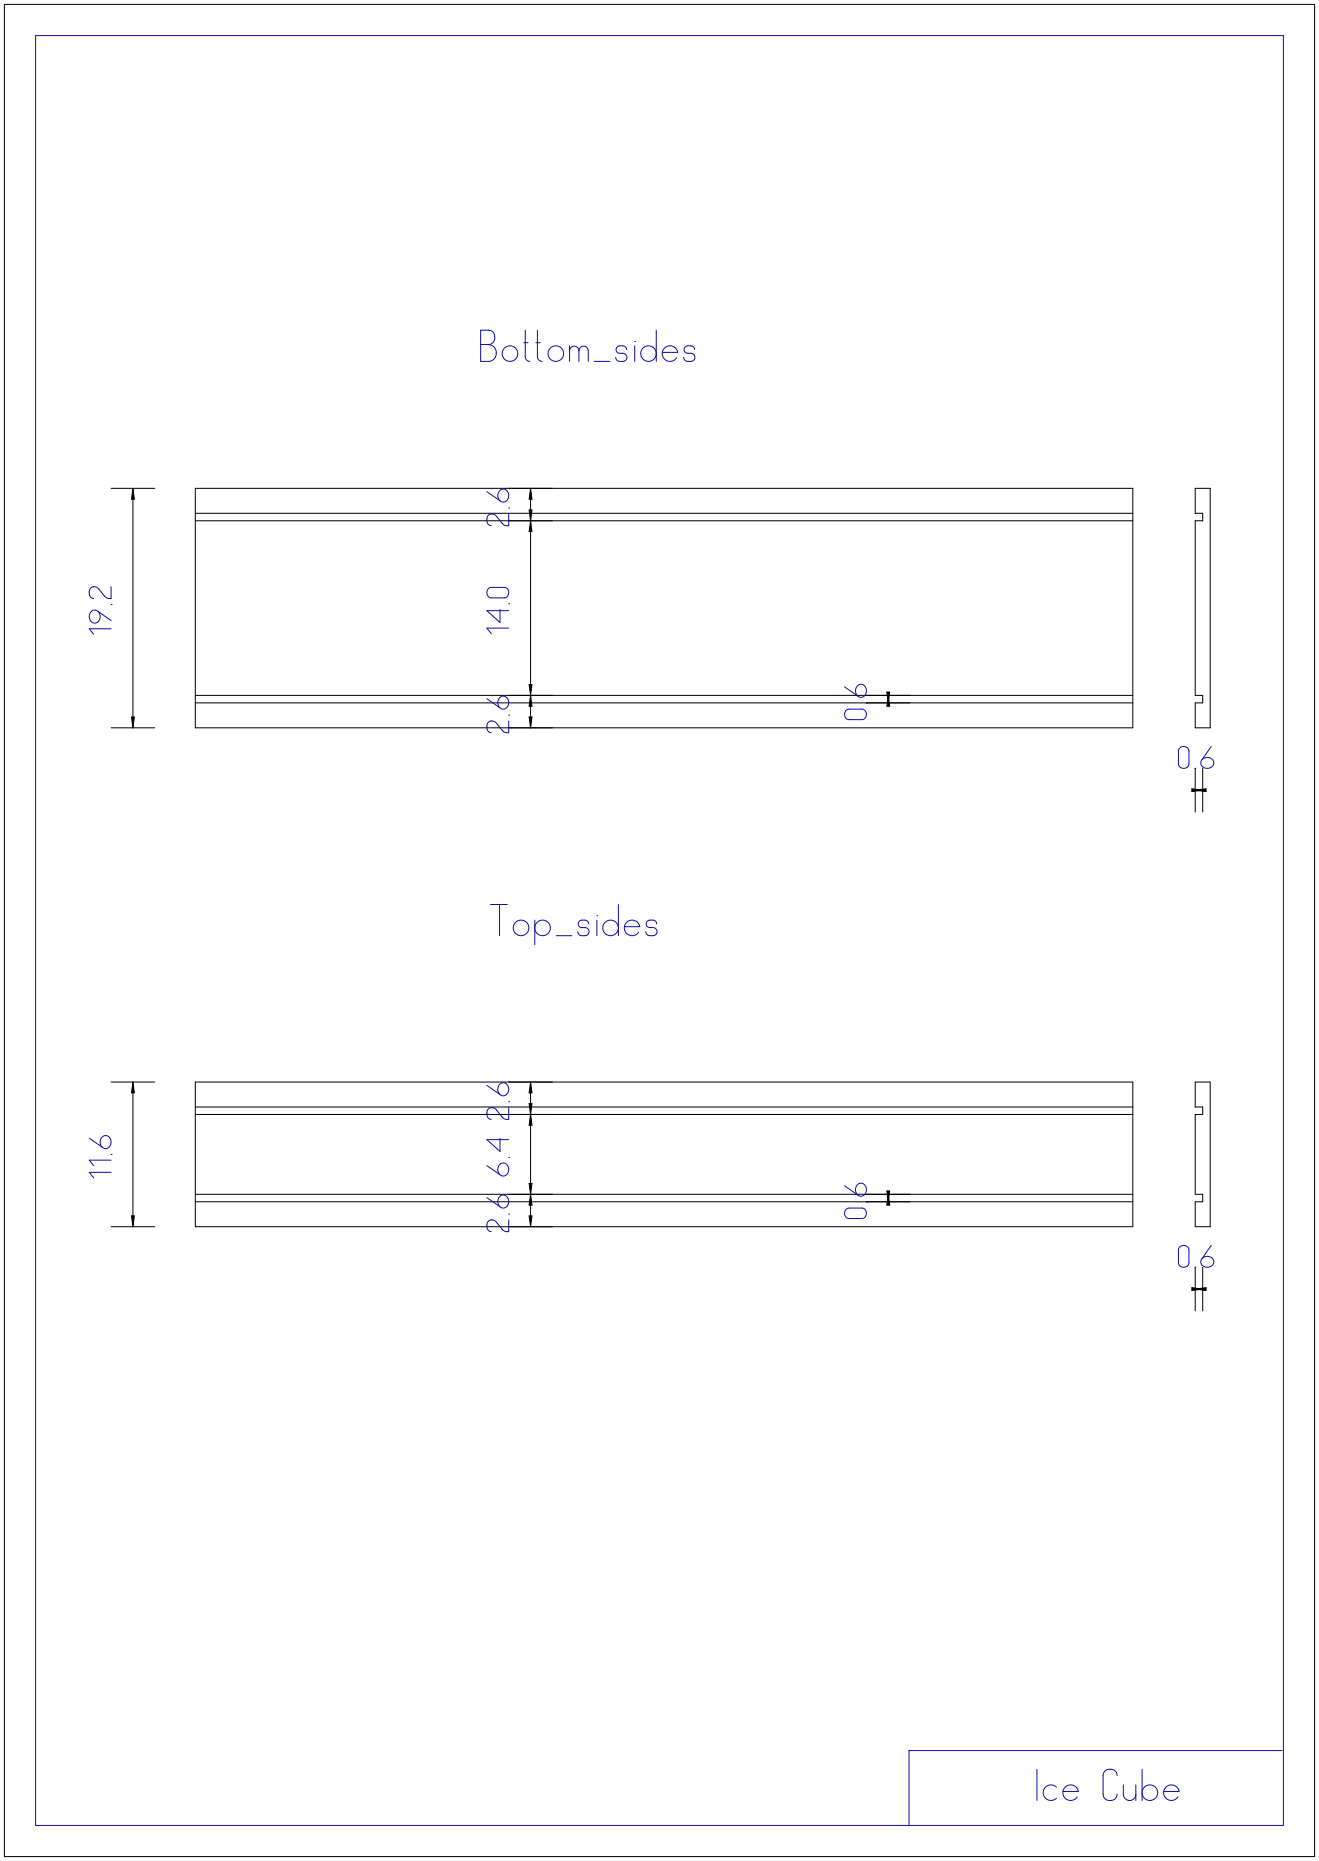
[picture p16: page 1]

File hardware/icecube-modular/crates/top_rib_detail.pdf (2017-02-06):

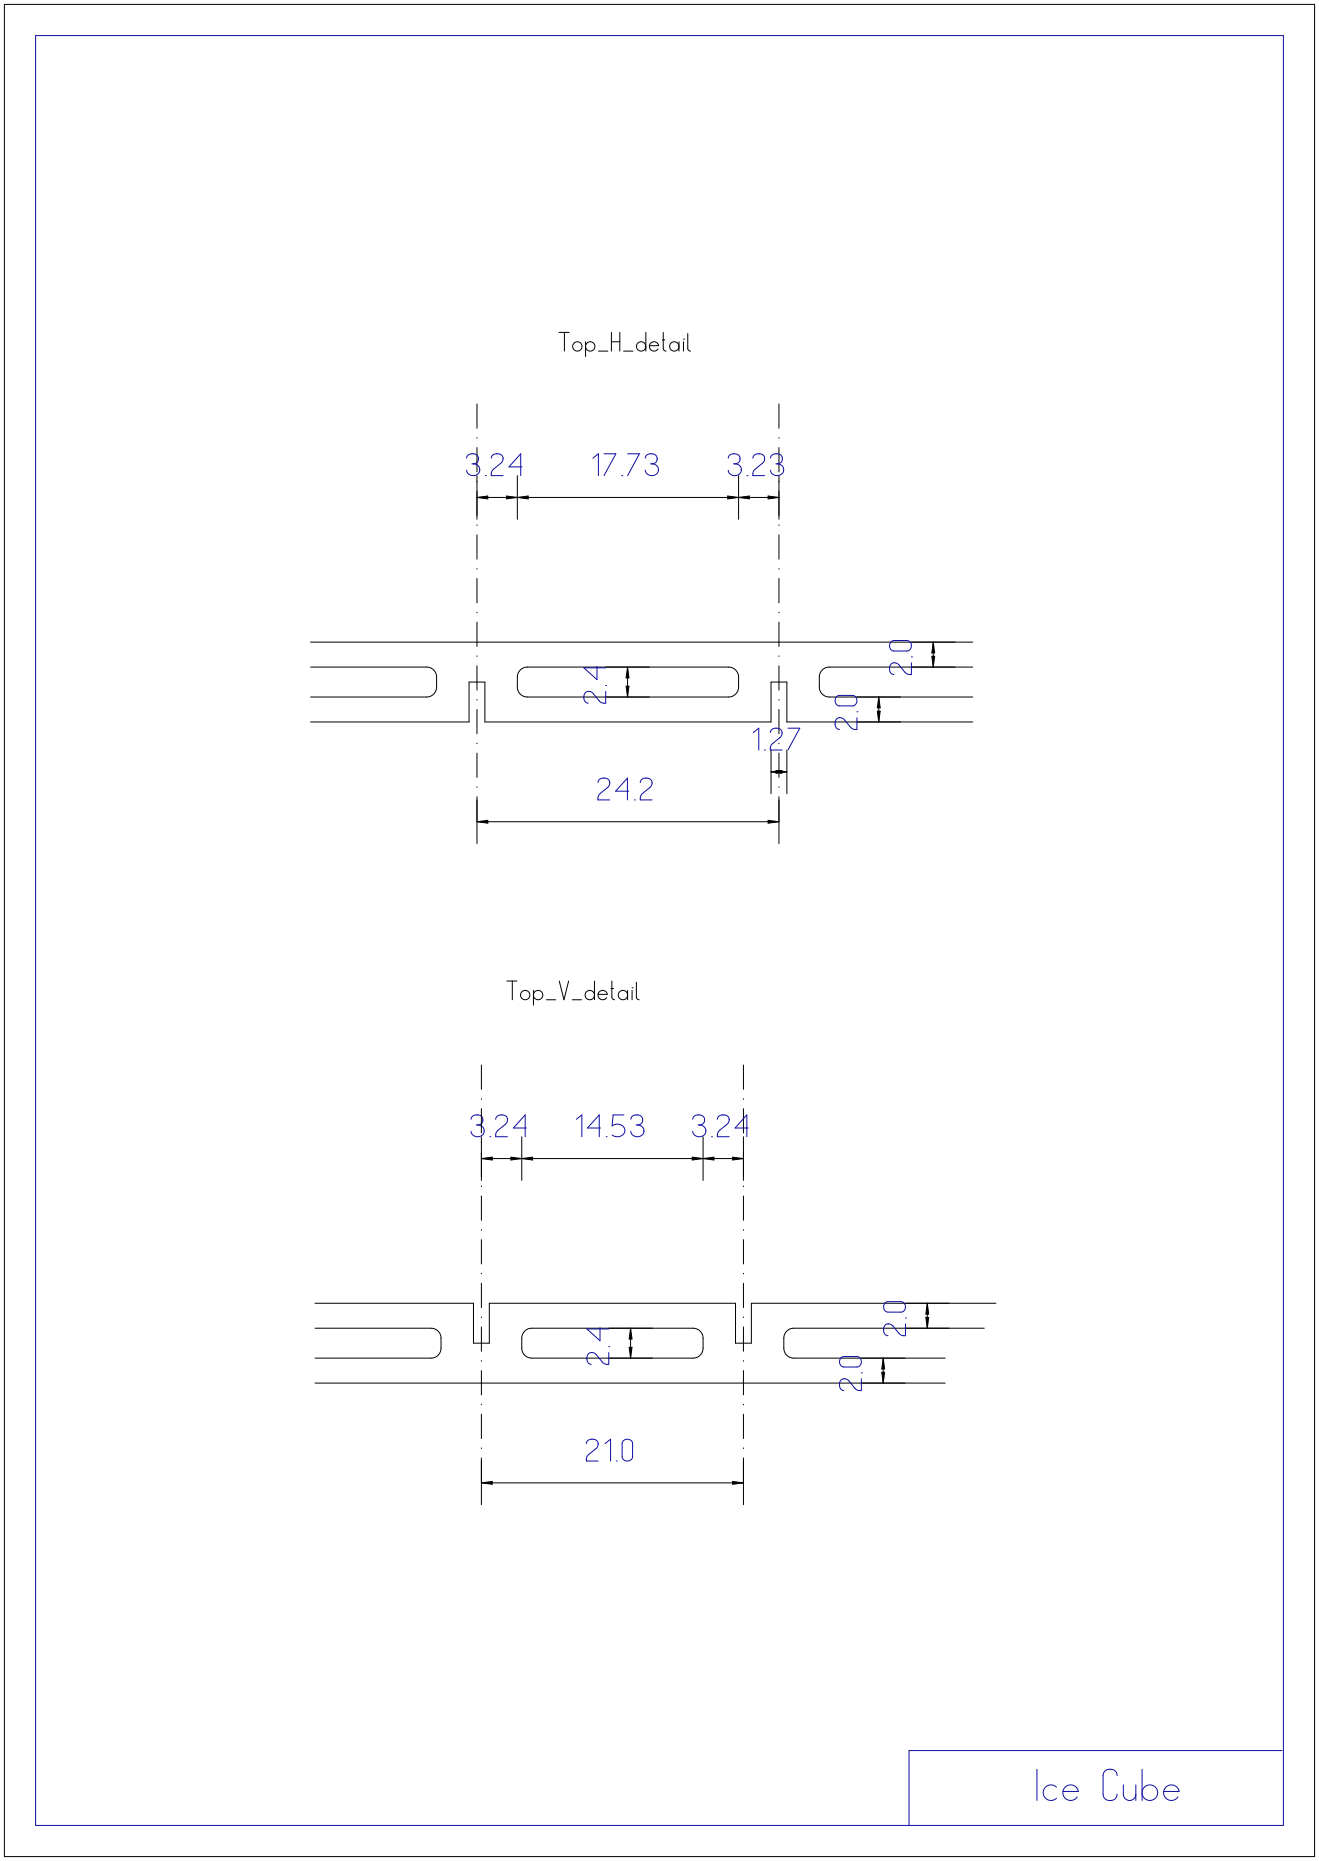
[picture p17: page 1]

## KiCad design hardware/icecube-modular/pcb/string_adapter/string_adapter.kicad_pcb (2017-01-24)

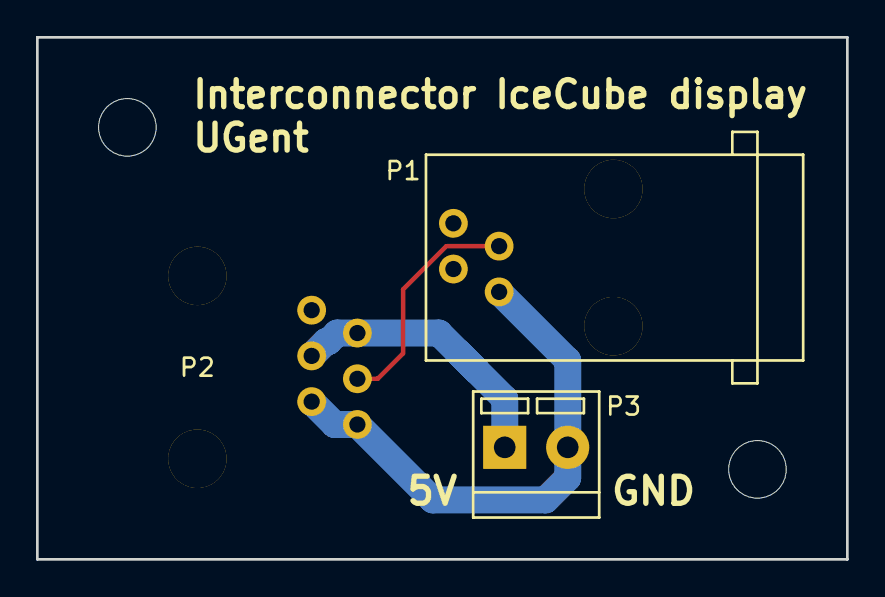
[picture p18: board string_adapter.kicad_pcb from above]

Board: 2 copper layers, 45.0 x 29.0 mm, 3 parts (1 on the bottom side), 3 nets.

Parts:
P1: 4P4C; 4P4C_horizontal
P2: 6P6C; 6P6C_vertical
P3: CONN_01X02; TerminalBlock_3.5mm_2pol

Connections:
/5V: P2.4, P2.5, P3.1
/DATA: P1.3, P2.3
/GND: P1.1, P2.1, P2.2, P3.2

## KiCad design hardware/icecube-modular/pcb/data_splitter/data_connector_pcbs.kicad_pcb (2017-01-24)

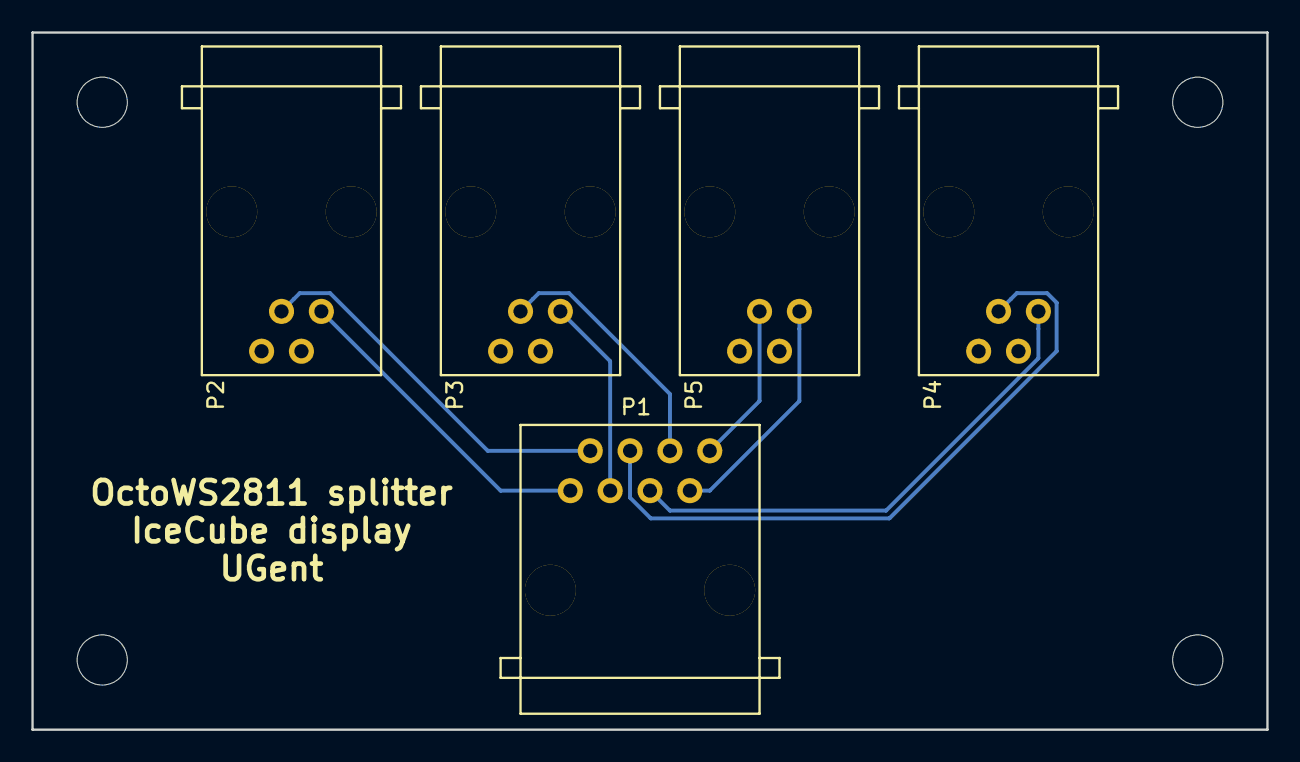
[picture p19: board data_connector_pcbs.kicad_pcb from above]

Board: 2 copper layers, 78.7 x 44.4 mm, 5 parts (0 on the bottom side), 8 nets.

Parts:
P1: 8P8C; 8P8C_horizontal
P2, P3, P4, P5: 4P4C; 4P4C_horizontal

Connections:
/D1: P1.2, P2.3
/D2: P1.6, P3.3
/D3: P1.4, P4.3
/D4: P1.8, P5.3
unnamed: P1.1, P2.1
unnamed: P1.3, P3.1
unnamed: P1.5, P4.1
unnamed: P1.7, P5.1

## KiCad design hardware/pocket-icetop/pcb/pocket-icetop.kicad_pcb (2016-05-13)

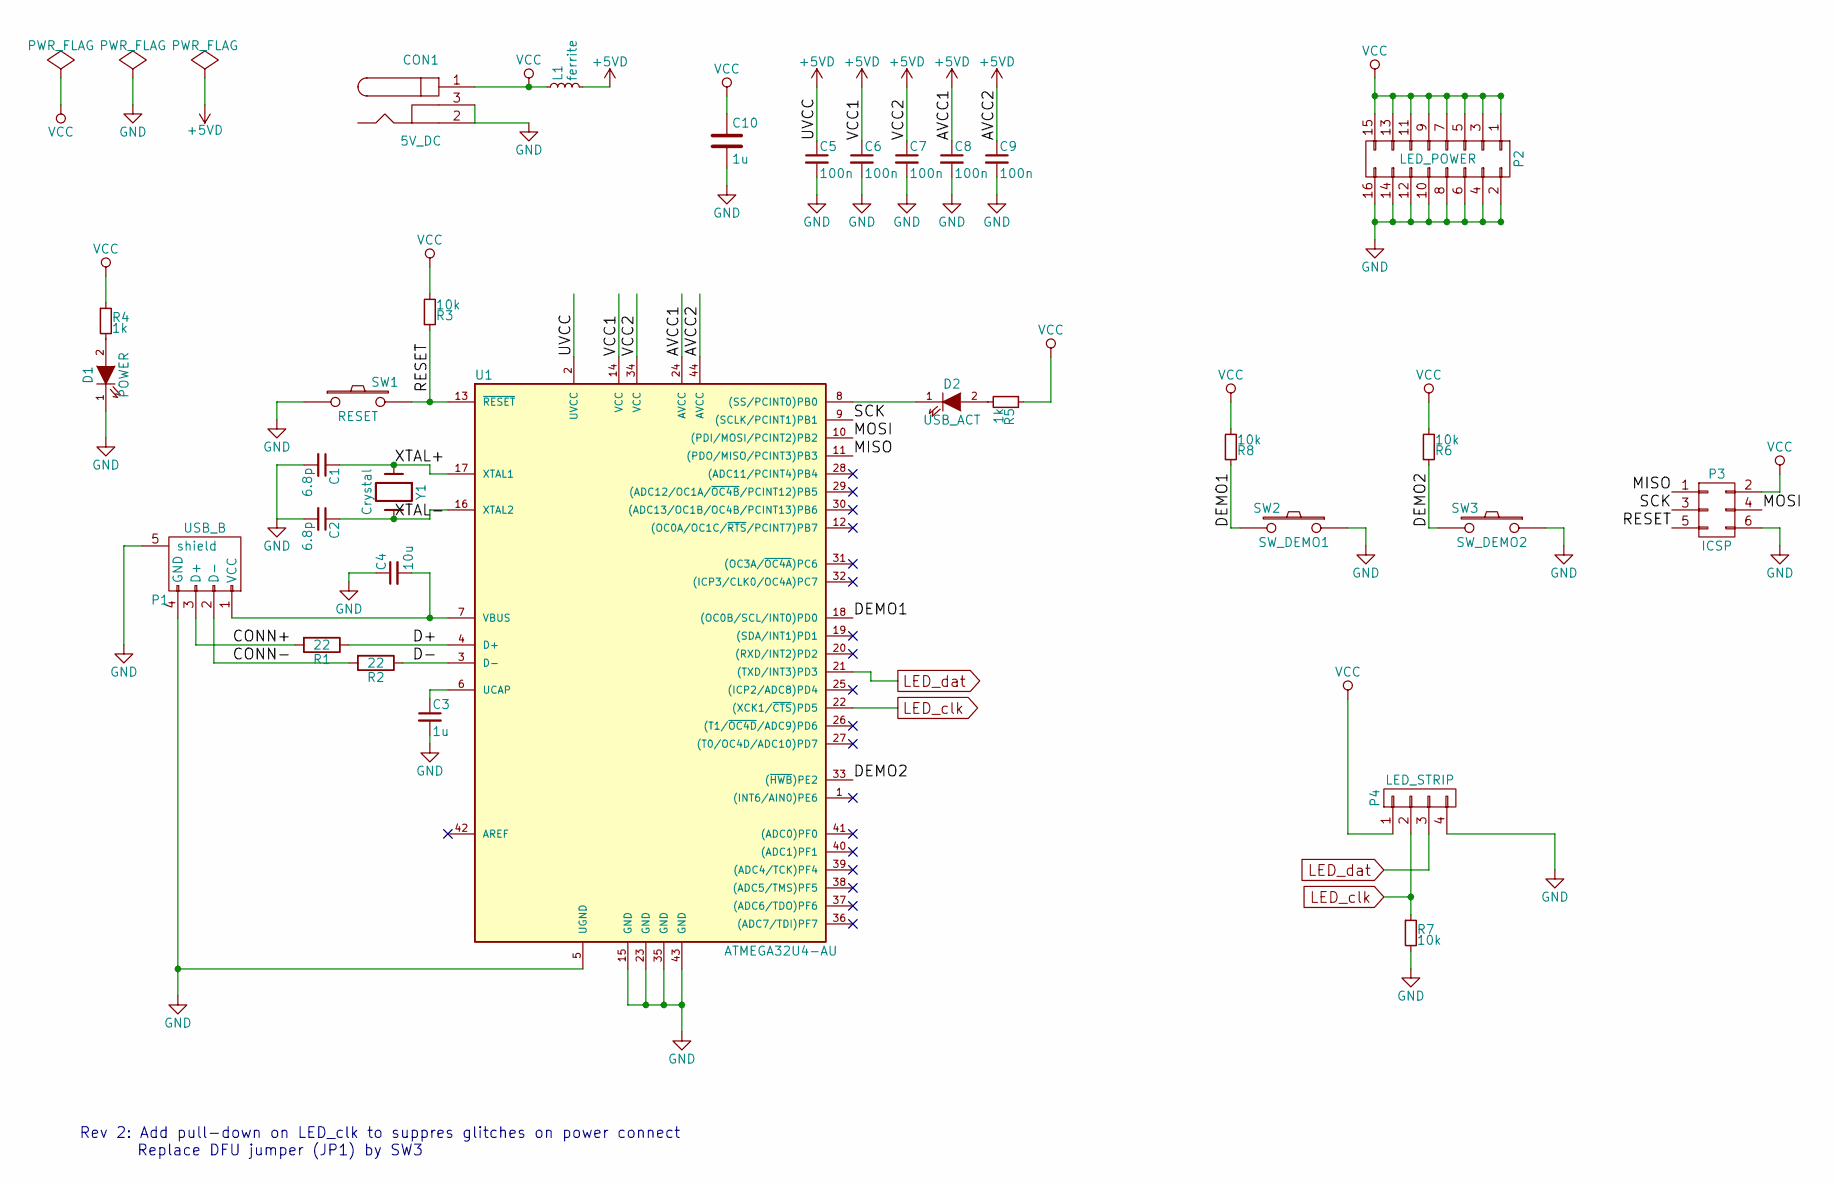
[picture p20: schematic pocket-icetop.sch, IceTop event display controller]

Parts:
C1, C2: 6.8p; C_0603_HandSoldering
C3: 1u; C_0603_HandSoldering
C4: 10u; C_0603_HandSoldering
C5, C6, C7, C8, C9: 100n; C_0603_HandSoldering
C10: 1u; C_0805_HandSoldering
CON1: 5V_DC; BARREL_JACK
D1: POWER; LED-3MM
D2: USB_ACT; LED-3MM
L1: ferrite; L_0603_HandSoldering
P1: USB_B
P2: LED_POWER; IDC_socket_2x08
P3: ICSP; Pin_Header_Straight_2x03
P4: LED_STRIP; Pin_Header_Straight_1x04
R1, R2: 22; R_0603_HandSoldering
R3, R6, R7, R8: 10k; R_0603_HandSoldering
R4, R5: 1k; R_0603_HandSoldering
SW1: RESET; SW_Tactile_SPST_Angled
SW2: SW_DEMO1; SW_Tactile_SPST_Angled
SW3: SW_DEMO2; SW_Tactile_SPST_Angled
U1: ATMEGA32U4-AU; TQFP-44_10x10mm_Pitch0.8mm
Y1: Crystal; Crystal_HC49-U_Vertical

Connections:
+5VD: C5.1, C6.1, C7.1, C8.1, C9.1, L1.2, U1.2 (UVCC), U1.14 (VCC), U1.24 (AVCC), U1.34 (VCC), U1.44 (AVCC)
/CONN+: P1.3 (D+), R1.2
/CONN-: P1.2 (D-), R2.2
/D+: R1.1, U1.4 (D+)
/D-: R2.1, U1.3 (D-)
/DEMO1: R8.1, SW2.2, U1.18 ((OC0B/SCL/INT0)PD0)
/DEMO2: R6.1, SW3.2, U1.33 ((~HWB~)PE2)
/MISO: P3.1, U1.11 ((PDO/MISO/PCINT3)PB3)
/MOSI: P3.4, U1.10 ((PDI/MOSI/PCINT2)PB2)
/RESET: P3.5, R3.1, SW1.2, U1.13 (~RESET~)
/SCK: P3.3, U1.9 ((SCLK/PCINT1)PB1)
/XTAL+: C1.1, U1.17 (XTAL1), Y1.1
/XTAL-: C2.1, U1.16 (XTAL2), Y1.2
GND: C1.2, C2.2, C3.2, C4.1, C5.2, C6.2, C7.2, C8.2, C9.2, C10.2, CON1.2, CON1.3, D1.1 (K), P1.4 (GND), P1.5 (shield), P2.2, P2.4, P2.6, P2.8, P2.10, P2.12, P2.14, P2.16, P3.6, P4.4, R7.2, SW1.1, SW2.1, SW3.1, U1.5 (UGND), U1.15 (GND), U1.23 (GND), U1.35 (GND), U1.43 (GND)
LED_clk: P4.2, R7.1, U1.22 ((XCK1/~CTS~)PD5)
LED_dat: P4.3, U1.21 ((TXD/INT3)PD3)
unnamed: C3.1, U1.6 (UCAP)
unnamed: C4.2, P1.1 (VCC), U1.7 (VBUS)
unnamed: D1.2 (A), R4.2
unnamed: D2.1 (K), U1.8 ((SS/PCINT0)PB0)
unnamed: D2.2 (A), R5.2
VCC: C10.1, CON1.1, L1.1, P2.1, P2.3, P2.5, P2.7, P2.9, P2.11, P2.13, P2.15, P3.2, P4.1, R3.2, R4.1, R5.1, R6.2, R8.2

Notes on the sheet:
Rev 2: Add pull-down on LED_clk to suppres glitches on power connect Replace DFU jumper (JP1) by SW3

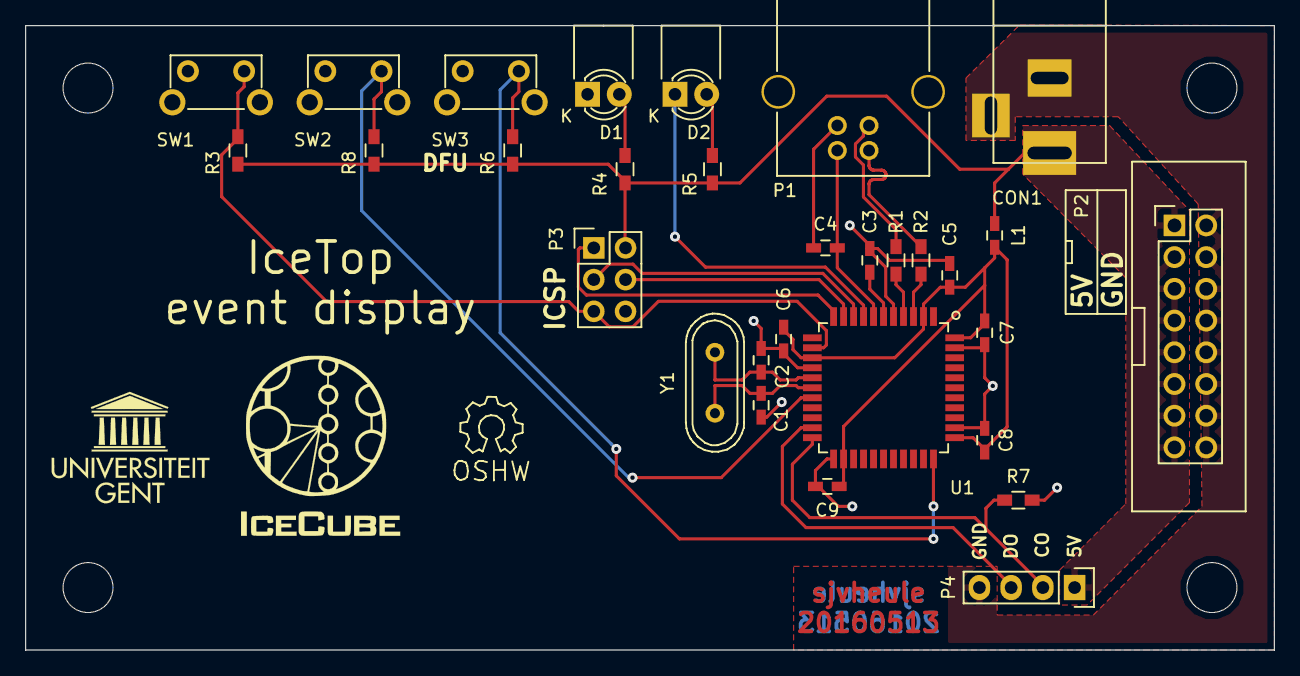
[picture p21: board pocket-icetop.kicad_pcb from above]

Board: 2 copper layers, 100.0 x 50.0 mm, 31 parts (1 on the bottom side), 22 nets.

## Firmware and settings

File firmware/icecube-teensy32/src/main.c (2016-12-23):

#include <stdint.h>

#include "display_driver.h"
#include "render/rain.h"
#include "remote.h"
#include "frame_buffer.h"
#include "frame_queue.h"
#include "frame_timer.h"

// Display state
enum display_state_t {
    DISPLAY_STATE_BOOT = 0
  , DISPLAY_STATE_IDLE
  , DISPLAY_STATE_BOOT_SPLASH
  , DISPLAY_STATE_EXTERNAL
};

static volatile enum display_state_t display_state = DISPLAY_STATE_BOOT;
static const struct renderer_t* volatile renderer = 0;
// If boot splash duration is > 0, display splash first.
// Otherwise go straight to idle.
static uint8_t boot_splash_duration = DEVICE_FPS-1;

static inline const struct renderer_t* get_renderer() {
  switch (display_state) {
#ifdef DEVICE_TEST_MODE
    case DISPLAY_STATE_IDLE:
#endif
    case DISPLAY_STATE_BOOT_SPLASH:
      return get_rain_renderer();
      break;
#ifndef DEVICE_TEST_MODE
    case DISPLAY_STATE_IDLE:
#endif
    case DISPLAY_STATE_BOOT:
    case DISPLAY_STATE_EXTERNAL:
    default:
      return 0;
      break;
  }
}

static inline void advance_display_state() {
  // By default, keep old state
  enum display_state_t new_state = display_state;

  if (display_state == DISPLAY_STATE_BOOT) {
    if (boot_splash_duration > 0) {
      new_state = DISPLAY_STATE_BOOT_SPLASH;
    }
    else {
      new_state = DISPLAY_STATE_IDLE;
    }
  }
  else if (display_state == DISPLAY_STATE_BOOT_SPLASH) {
    if (boot_splash_duration > 0) {
      --boot_splash_duration;
    }
    else {
      new_state = DISPLAY_STATE_IDLE;
    }
  }
  else if (display_state == DISPLAY_STATE_IDLE && is_remote_connected()) {
    new_state = DISPLAY_STATE_EXTERNAL;
  }
  else if (display_state == DISPLAY_STATE_EXTERNAL && !is_remote_connected()) {
    new_state = DISPLAY_STATE_IDLE;
  }

  // Check if state changed and switch renderers accordingly
  if (new_state != display_state) {
    // Stop current renderer
    if (renderer && renderer->stop) {
      renderer->stop();
    }
    // Select new renderer
    display_state = new_state;
    renderer = get_renderer();
    // Init new renderer
    if (renderer) {
      if (renderer->start) {
        renderer->start();
      }
    }
    else {
      struct frame_buffer_t* f = create_empty_frame();
      if (f) {
        f->flags |= FRAME_FREE_AFTER_DRAW;
        if (!push_frame(f)) {
          destroy_frame(f);
        }
      }
    }
  }
}


static inline void consume_frame(struct frame_buffer_t* frame) {
  if (frame && frame->buffer) {
    display_frame(frame);
    if (frame->flags & FRAME_FREE_AFTER_DRAW) {
      destroy_frame(frame);
    }
  }
}

int main () {
  // Must be run *before* using any other display functions
  init_display_properties();

  // Initialise frame buffer memory before rendering
  init_frame_buffers();

  // Init display pin configuration
  init_display_driver();
  display_blank();

  // Init remote communications module
  init_remote();

  // Init display timer just before display loop
  init_frame_timer();

  // Main loop
  for (;;) {
    while (!should_draw_frame()) {
      // Idle CPU until next interrupt
      asm("wfi");
    }

    consume_frame(pop_frame());

    advance_display_state();

    if (renderer && !frame_queue_full()) {
      struct frame_buffer_t* f = renderer->render_frame();
      if (f && !push_frame(f) && (f->flags & FRAME_FREE_AFTER_DRAW)) {
        destroy_frame(f);
      }
    }

    clear_draw_frame();
  }

  return 0;
}

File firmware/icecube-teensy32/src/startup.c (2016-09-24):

/* Teensyduino Core Library
 * http://www.pjrc.com/teensy/
 * Copyright (c) 2013 PJRC.COM, LLC.
 *
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
 * 2. If the Software is incorporated into a build system that allows 
 * selection among a list of target devices, then similar target
 * devices manufactured by PJRC.COM must be included in the list of
 * target devices and selectable in the same manner.
 *
 * THE SOFTWARE IS PROVIDED "AS IS", WITHOUT WARRANTY OF ANY KIND,
 * EXPRESS OR IMPLIED, INCLUDING BUT NOT LIMITED TO THE WARRANTIES OF
 * MERCHANTABILITY, FITNESS FOR A PARTICULAR PURPOSE AND
 * NONINFRINGEMENT. IN NO EVENT SHALL THE AUTHORS OR COPYRIGHT HOLDERS
 * BE LIABLE FOR ANY CLAIM, DAMAGES OR OTHER LIABILITY, WHETHER IN AN
 * ACTION OF CONTRACT, TORT OR OTHERWISE, ARISING FROM, OUT OF OR IN
 * CONNECTION WITH THE SOFTWARE OR THE USE OR OTHER DEALINGS IN THE
 * SOFTWARE.
 */

#include "kinetis.h"


// Flash Security Setting. On Teensy 3.2, you can lock the MK20 chip to prevent
// anyone from reading your code. The bootloader will be unable to respond to
// auto-reboot requests from Arduino. Pressing the program button will cause a
// full chip erase, because the bootloader chip is locked out.  Normally, erase
// occurs when uploading begins, so if you press the Program button accidentally,
// simply power cycling will run your program again.  When security is locked,
// any Program button press causes immediate full erase.  To set the security
// lock, change this to 0xDC.  Teensy 3.0 and 3.1 do not support security lock.
#define FSEC 0xDE

// Flash Options
#define FOPT 0xF9


extern unsigned long _stext;
extern unsigned long _etext;
extern unsigned long _sdata;
extern unsigned long _edata;
extern unsigned long _sbss;
extern unsigned long _ebss;
extern unsigned long _estack;
//extern void __init_array_start(void);
//extern void __init_array_end(void);



extern int main (void);
void ResetHandler(void);
void __libc_init_array(void);


void fault_isr(void)
{
#if 0
	uint32_t addr;

	SIM_SCGC4 |= 0x00000400;
	UART0_BDH = 0;
	UART0_BDL = 26; // 115200 at 48 MHz
	UART0_C2 = UART_C2_TE;
	PORTB_PCR17 = PORT_PCR_MUX(3);
	ser_print("\nfault: \n??: ");
        asm("ldr %0, [sp, #52]" : "=r" (addr) ::);
        ser_print_hex32(addr);
        ser_print("\n??: ");
        asm("ldr %0, [sp, #48]" : "=r" (addr) ::);
        ser_print_hex32(addr);
        ser_print("\n??: ");
        asm("ldr %0, [sp, #44]" : "=r" (addr) ::);
        ser_print_hex32(addr);
        ser_print("\npsr:");
        asm("ldr %0, [sp, #40]" : "=r" (addr) ::);
        ser_print_hex32(addr);
        ser_print("\nadr:");
        asm("ldr %0, [sp, #36]" : "=r" (addr) ::);
        ser_print_hex32(addr);
        ser_print("\nlr: ");
        asm("ldr %0, [sp, #32]" : "=r" (addr) ::);
        ser_print_hex32(addr);
        ser_print("\nr12:");
        asm("ldr %0, [sp, #28]" : "=r" (addr) ::);
        ser_print_hex32(addr);
        ser_print("\nr3: ");
        asm("ldr %0, [sp, #24]" : "=r" (addr) ::);
        ser_print_hex32(addr);
        ser_print("\nr2: ");
        asm("ldr %0, [sp, #20]" : "=r" (addr) ::);
        ser_print_hex32(addr);
        ser_print("\nr1: ");
        asm("ldr %0, [sp, #16]" : "=r" (addr) ::);
        ser_print_hex32(addr);
        ser_print("\nr0: ");
        asm("ldr %0, [sp, #12]" : "=r" (addr) ::);
        ser_print_hex32(addr);
        ser_print("\nr4: ");
        asm("ldr %0, [sp, #8]" : "=r" (addr) ::);
        ser_print_hex32(addr);
        ser_print("\nlr: ");
        asm("ldr %0, [sp, #4]" : "=r" (addr) ::);
        ser_print_hex32(addr);
        ser_print("\n");
        asm("ldr %0, [sp, #0]" : "=r" (addr) ::);
#endif
	while (1) {
		// keep polling some communication while in fault
		// mode, so we don't completely die.
		if (SIM_SCGC4 & SIM_SCGC4_USBOTG) usb_isr();
		if (SIM_SCGC4 & SIM_SCGC4_UART0) uart0_status_isr();
		if (SIM_SCGC4 & SIM_SCGC4_UART1) uart1_status_isr();
		if (SIM_SCGC4 & SIM_SCGC4_UART2) uart2_status_isr();
	}
}

void unused_isr(void)
{
	fault_isr();
}

void nmi_isr(void)		__attribute__ ((weak, alias("unused_isr")));
void hard_fault_isr(void)	__attribute__ ((weak, alias("fault_isr")));
void memmanage_fault_isr(void)	__attribute__ ((weak, alias("fault_isr")));
void bus_fault_isr(void)	__attribute__ ((weak, alias("fault_isr")));
void usage_fault_isr(void)	__attribute__ ((weak, alias("fault_isr")));
void svcall_isr(void)		__attribute__ ((weak, alias("unused_isr")));
void debugmonitor_isr(void)	__attribute__ ((weak, alias("unused_isr")));
void pendablesrvreq_isr(void)	__attribute__ ((weak, alias("unused_isr")));
void systick_isr(void)		__attribute__ ((weak, alias("unused_isr")));
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

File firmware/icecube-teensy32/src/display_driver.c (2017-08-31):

#include <stdint.h>
#include <stdbool.h>
#include <stdalign.h>
#include <stdatomic.h>

#include "kinetis/io.h"
#include "kinetis/ftm.h"
#include "kinetis/dma.h"
#include <avr/eeprom.h>

#include "display_driver.h"
#include "display_properties.h"
#include "device_properties.h"
#include "display_types.h"


// Buffer dimensions
#define STRING_LENGTH 60
#define SEGMENT_COUNT 4
#define STRIP_LENGTH (STRING_LENGTH*SEGMENT_COUNT)

#define MAX_PORT_COUNT 8

#define BUFFER_STEP sizeof(struct led_t)
#define BUFFER_SIZE (MAX_PORT_COUNT*STRIP_LENGTH*sizeof(struct led_t))

// Color order
#define OFFSET_RED ((ptrdiff_t) offsetof(struct led_t, red))
#define OFFSET_GREEN ((ptrdiff_t) offsetof(struct led_t, green))
#define OFFSET_BLUE ((ptrdiff_t) offsetof(struct led_t, blue))

static ptrdiff_t color_offset_initial;
static ptrdiff_t delta_0;
static ptrdiff_t delta_1;

// Strip orientation
static bool reverse_first_segment;

// LED strip to buffer offset mapping
struct port_map_t {
  uint8_t ports_length;
  uint8_t ports[MAX_PORT_COUNT];
};

// LED layout stored in EEPROM
#define PORTMAP __attribute__((section(".portmap"),used))
static const struct port_map_t LED_MAP[SEGMENT_COUNT] PORTMAP;

static struct port_map_t led_mapping[SEGMENT_COUNT];

static volatile atomic_flag frame_write_in_progress;

// DMA sources
#define DISPMEM __attribute__ ((section(".displaybuffer")))
static alignas(4) uint8_t ones DISPMEM;
static alignas(4) uint8_t led_data[BUFFER_SIZE] DISPMEM;

// Defaoult FTM channel configuration
static const uint32_t ftm_channel_output = _BV(5)|_BV(3);

// OctoWS2811 init_display_driver
void init_display_driver() {
  /** Based on OctoWS2811 code **/

  // Initialise data output port
  ATOMIC_REGISTER_BIT_SET(SIM_SCGC5, 12); // Enable port D clock
  PORTD_GPCLR = (0xFFFF<<16) | (1<<8); // Select ALT1 (GPIO) mode for all pins
  PORTD_GPCHR = (0xFFFF<<16); // Disable all interrupts on port D
  GPIOD_PDDR = 0xFF; // Set all port pins as output
  GPIOD_PCOR = 0xFF; // Clear all pin outputs

  // Initialise DMA
  ATOMIC_REGISTER_BIT_SET(SIM_SCGC6, 1); // SIM_SCGC6(1) DMA mux module
  ATOMIC_REGISTER_BIT_SET(SIM_SCGC7, 1); // SIM_SCGC7(1) DMA module

  DMA_CR = _BV(7);
  DMA_ERQ = 0;
  DMA_EEI = 0;
  clear_channel_tcd(0);
  clear_channel_tcd(1);
  clear_channel_tcd(2);

  // Initialise ones to 0xFF since the .displaybuffer section is not initialised
  ones = 0xFF;

  // Set all outputs high at start of pulse
  dma_tcd_list[0].CSR = _BV(3);
  dma_tcd_list[0].SADDR = &ones;
  dma_tcd_list[0].DADDR = &GPIOD_PSOR;
  dma_tcd_list[0].NBYTES = 1;
  dma_tcd_list[0].BITER = BUFFER_SIZE;
  dma_tcd_list[0].CITER = BUFFER_SIZE;

  // Write bit values after time_0_high
  // SADDR, SOFF, SLAST and DADDR are set when initiating a frame write
  dma_tcd_list[1].CSR = _BV(3);
  dma_tcd_list[1].NBYTES = 1;
  dma_tcd_list[1].BITER = BUFFER_SIZE;
  dma_tcd_list[1].CITER = BUFFER_SIZE;

  // Set all outputs low after time_1_high
  dma_tcd_list[2].CSR = _BV(3) | _BV(1);
  dma_tcd_list[2].SADDR = &ones;
  dma_tcd_list[2].DADDR = &GPIOD_PCOR;
  dma_tcd_list[2].NBYTES = 1;
  dma_tcd_list[2].BITER = BUFFER_SIZE;
  dma_tcd_list[2].CITER = BUFFER_SIZE;

  // Disable used DMA channels
  DMAMUX0_CHCFG0 = 0;
  DMAMUX0_CHCFG2 = 0;
  DMAMUX0_CHCFG1 = 0;

  ATOMIC_REGISTER_BIT_SET(SIM_SCGC3, 24); // SIM_SCGC3(24) for FTM2

  /* Datasheet for the WS2812B ICs specifies a pulse interval of 1.25µs.
   * high durations for 0s should be 0.4µs (32%)
   * high durations for 1s should be 0.8µs (64%)
   *
   * The OctoWS2811 library uses the following high durations:
   * 0:  60/256 (23%); smaller than spec to allow for jitter on reading the RAM values
   * 1: 176/256 (69%); slightly longer than spec
   * Another recommendation seen on the interwebs is to use a slightly longer pulse period, e.g.
   * 110%. This is to reduce flicker when, due to bus latency, the low-time between two subsequent
   * bits becomes too short for the ICs to recognise it. The IC's then read 1s, resulting in the
   * display flashing.
   */
#ifdef USE_STANDARD_TIMING
  const uint16_t counter_total = (F_BUS/F_LED);
  const uint16_t count_0_high = 0.4/1.25*(F_BUS/F_LED);
  const uint16_t count_1_high = 0.8/1.25*(F_BUS/F_LED);
#else
  const uint16_t counter_total = 1.1*((F_BUS+F_LED/2)/F_LED);
  const uint16_t count_0_high = 0.30/1.25*((F_BUS+F_LED/2)/F_LED);
  const uint16_t count_1_high = 0.86/1.25*((F_BUS+F_LED/2)/F_LED);
#endif

  ftm2_config->SC = 0;
  ftm2_config->MOD = counter_total-1;

  ftm2_config->channels[0].SC = ftm_channel_output;
  ftm2_config->channels[1].SC = ftm_channel_output;

  ftm2_config->channels[0].VAL = count_0_high-1;
  ftm2_config->channels[1].VAL = count_1_high-1;

  // Configure port B(18) as FTM2_CH0 output to be able to trigger a DMA request on its rising edge
  ATOMIC_REGISTER_BIT_SET(SIM_SCGC5, 10);
  PORTD_GPCHR = (0xF<<16); // Disable all interrupts on port B
  PORTB_PCR18 = (1<<16) | (3<<8);

  // Enable DMA channels
  DMAMUX0_CHCFG0 = 50 | _BV(7); // Ch 50 = port B
  DMAMUX0_CHCFG1 = 34 | _BV(7); // Ch 34 = FTM2_CH0
  DMAMUX0_CHCFG2 = 35 | _BV(7); // Ch 34 = FTM2_CH1

  // Read color order and determine pointer differences
  switch (get_color_order()) {
    case LED_ORDER_BGR:
      color_offset_initial = OFFSET_BLUE;
      delta_0 = OFFSET_GREEN-OFFSET_BLUE;
      delta_1 = OFFSET_RED-OFFSET_GREEN;
      break;
    case LED_ORDER_BRG:
      color_offset_initial = OFFSET_BLUE;
      delta_0 = OFFSET_RED-OFFSET_BLUE;
      delta_1 = OFFSET_GREEN-OFFSET_RED;
      break;
    case LED_ORDER_GBR:
      color_offset_initial = OFFSET_GREEN;
      delta_0 = OFFSET_BLUE-OFFSET_GREEN;
      delta_1 = OFFSET_RED-OFFSET_BLUE;
      break;
    case LED_ORDER_GRB:
      color_offset_initial = OFFSET_GREEN;
      delta_0 = OFFSET_RED-OFFSET_GREEN;
      delta_1 = OFFSET_BLUE-OFFSET_RED;
      break;
    case LED_ORDER_RBG:
      color_offset_initial = OFFSET_RED;
      delta_0 = OFFSET_BLUE-OFFSET_RED;
      delta_1 = OFFSET_GREEN-OFFSET_BLUE;
      break;
    case LED_ORDER_RGB:
    default:
      color_offset_initial = OFFSET_RED;
      delta_0 = OFFSET_GREEN-OFFSET_RED;
      delta_1 = OFFSET_BLUE-OFFSET_GREEN;
      break;
  }

  eeprom_read_block(&led_mapping, &LED_MAP, sizeof(LED_MAP));
  for (unsigned int segment = 0; segment < SEGMENT_COUNT; ++segment) {
    if (led_mapping[segment].ports_length > MAX_PORT_COUNT) {
      led_mapping[segment].ports_length = 0;
    }
  }

  // Strip orientation
  reverse_first_segment = get_reverse_first_strip_segment();

  // PDB configuration for frame reset timer
  ATOMIC_REGISTER_BIT_SET(SIM_SCGC6, 22); // Enable PDB clock
  PDB0_SC = PDB_SC_PDBIE | PDB_SC_TRGSEL(15);
  NVIC_ENABLE_IRQ(IRQ_PDB);
  // 50 µs delay (equiv 20000/s) with 48MHz F_BUS: 2400 counts (no prescaler required)
  const uint16_t reset_delay_counts = (F_BUS/20000);
  PDB0_MOD = reset_delay_counts - 1;
  PDB0_IDLY = reset_delay_counts - 1;

  PDB0_SC = PDB_SC_PDBIE | PDB_SC_TRGSEL(15) | PDB_SC_LDOK | PDB_SC_PDBEN;
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

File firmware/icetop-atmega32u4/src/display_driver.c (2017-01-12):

#include <avr/io.h>
#include <avr/pgmspace.h>
#include <stdint.h>
#include "display_types.h"
#include "display_driver.h"
#include "display_properties.h"

// See pocket_icetop.dxf
static const uint8_t LED_MAP_IT78[LED_COUNT_IT78] PROGMEM = {
              5,  4,  3,  2,  1,  0
          ,  6,  7,  8,  9, 10, 11, 12
        , 20, 19, 18, 17, 16, 15, 14, 13
      , 21, 22, 23, 24, 25, 26, 27, 28, 29
    , 39, 38, 37, 36, 35, 34, 33, 32, 31, 30
  , 40, 41, 42, 43, 44, 45, 46, 47, 48, 49
    , 58, 57, 56, 55, 54, 53, 52, 51, 50
      , 59, 60, 61, 62, 63, 64, 65, 66
        , 73, 72, 71, 70, 69, 68, 67
          , 74, 75, 76, 77
};

// See pocket_icetop_large.dxf
static const uint8_t LED_MAP_IT81[LED_COUNT_IT81] PROGMEM = {
              5,  4,  3,  2,  1,  0
          ,  6,  7,  8,  9, 10, 11, 12
        , 20, 19, 18, 17, 16, 15, 14, 13
      , 21, 22, 23, 24, 25, 26, 27, 28, 29
    , 39, 38, 37, 80, 35, 79, 36, 78, 34, 33, 32, 31, 30
  , 40, 41, 42, 43, 44, 45, 46, 47, 48, 49
    , 58, 57, 56, 55, 54, 53, 52, 51, 50
      , 59, 60, 61, 62, 63, 64, 65, 66
        , 73, 72, 71, 70, 69, 68, 67
          , 74, 75, 76, 77
};

static uint8_t led_count;
static const uint8_t* led_mapping_P;

/* Pre-calculated differential offsets between LED color components.
 * Since the LED chips might need the RGB data in a different order than the one that is stored
 * in RAM, calculate and store the pointer differences in the required order.
 * If an led_t object L is stored at address A, then L.red is stored at A+1, etc.
 * The jump_c[1-3] variables store the differences between the transmitted RGB components.
 * If the tranmission order is blue, green, red for example, jump_c[1-3] will be [3,-1,-1].
 * This corresponds to reading the data at [A, A+3, A+2, A+1]
 */
static int8_t jump_c1;
static int8_t jump_c2;
static int8_t jump_c3;

#define OFFSET_RED ((int8_t) offsetof(struct led_t, red))
#define OFFSET_GREEN ((int8_t) offsetof(struct led_t, green))
#define OFFSET_BLUE ((int8_t) offsetof(struct led_t, blue))


/* Since the display uses a number of APA102 LEDs connected in series, a hardware SPI
 * master port can be used to drive the LED chain. On an ATmega microcontroller, this can be
 * either a hardware SPI port, or a USART port configured as SPI master. The latter case allows
 * for lower transmission times as it has a hardware buffer that can be kept filled during
 * transmission. When using a SPI port, the buffer is only the size of the currently transmitted
 * byte, so one has to wait (and check) until the byte is transmitted to load the next byte,
 * introducing a small delay between bytes.
 */
void init_display_driver() {
  /* ATmega32U4 design uses the USART port in master SPI mode to drive the LED string.
   * The USART pins are located on port D:
   * * D2: RXD1 (MISO, in, unused)
   * * D3: TXD1 (MOSI, out)
   * * D5: XCK1 (SCK, out)
   */
#define SPI_BAUD_RATE 4000000UL
  DDRD |= _BV(DDD5) | _BV(DDD3);
  // USART as master SPI
  UCSR1B = _BV(TXEN1);
  UCSR1C = _BV(UMSEL11) | _BV(UMSEL10);
  // Set baud rate to 4M, using 16MHz system clock
  const uint16_t baud_rate_register = ((F_CPU + SPI_BAUD_RATE)/(2*SPI_BAUD_RATE) - 1);
  UBRR1H = (uint8_t) ((baud_rate_register >> 8) & 0x0F);
  UBRR1L = (uint8_t) baud_rate_register;
#undef SPI_BAUD_RATE

  // Load LED layout settings
  led_count = get_led_count();
  switch (led_count) {
    case LED_COUNT_IT78:
      led_mapping_P = LED_MAP_IT78;
      break;
    case LED_COUNT_IT81:
      led_mapping_P = LED_MAP_IT81;
      break;
    default:
      led_count = 0;
      led_mapping_P = 0;
      break;
  }

  switch (get_color_order()) {
    case LED_ORDER_BGR:
      jump_c1 = OFFSET_BLUE;
      jump_c2 = OFFSET_GREEN-OFFSET_BLUE;
      jump_c3 = OFFSET_RED-OFFSET_GREEN;
      break;
    case LED_ORDER_BRG:
      jump_c1 = OFFSET_BLUE;
      jump_c2 = OFFSET_RED-OFFSET_GREEN;
      jump_c3 = OFFSET_GREEN-OFFSET_RED;
      break;
    case LED_ORDER_GBR:
      jump_c1 = OFFSET_GREEN;
      jump_c2 = OFFSET_BLUE-OFFSET_GREEN;
      jump_c3 = OFFSET_RED-OFFSET_BLUE;
      break;
    case LED_ORDER_GRB:
      jump_c1 = OFFSET_GREEN;
      jump_c2 = OFFSET_RED-OFFSET_GREEN;
      jump_c3 = OFFSET_BLUE-OFFSET_RED;
      break;
    case LED_ORDER_RBG:
      jump_c1 = OFFSET_RED;
      jump_c2 = OFFSET_BLUE-OFFSET_RED;
      jump_c3 = OFFSET_GREEN-OFFSET_BLUE;
      break;
    case LED_ORDER_RGB:
      jump_c1 = OFFSET_RED;
      jump_c2 = OFFSET_GREEN-OFFSET_RED;
      jump_c3 = OFFSET_BLUE-OFFSET_GREEN;
      break;
  }

}

static inline void wait_write_finish() __attribute__((always_inline));
static inline void wait_write_finish() {
  // Check transmission finished bit
  while ( !(UCSR1A & _BV(UDRE1)) ) {}
}

static inline void write_byte_no_block(const uint8_t byte) __attribute__((always_inline));
static inline void write_byte_no_block(const uint8_t byte) {
  UDR1 = byte;
}

static inline void write_byte(const uint8_t byte) __attribute__((always_inline));
static inline void write_byte(const uint8_t byte) {
  // Write next byte
  write_byte_no_block(byte);
  // Wait for write to finish
  wait_write_finish();
}


/* # APA102C
 * Transmit bytes with MSB first
 * Data frame
 * * frame start: 4 bytes 0x00
 * * led data: (111X:XXXX BBBB:BBBB GGGG:GGGG RRRR:RRRR)
 *   * '111' header + 5 bits global brightness
 *   * blue, green, red
 * * frame end: ceil(n/2) '1' bits, or ceil(n/2/8) 0xFF bytes
 */

static inline void write_frame_header() __attribute__((always_inline));
static inline void write_frame_header() {
  const uint8_t FRAME_HEADER = 0x00;
  for (uint8_t i = 0; i < 4; ++i) {
    write_byte(FRAME_HEADER);
  }
}

static inline void write_frame_footer() __attribute__((always_inline));
static inline void write_frame_footer() {
  const uint8_t FRAME_FOOTER = 0xFF;
  for (uint8_t i = 0; i < led_count; i+=16) {
    write_byte(FRAME_FOOTER);
  }
}

const uint8_t LED_HEADER = 0xE0;

void display_frame(struct frame_buffer_t* frame) {
  frame->flags |= FRAME_DRAW_IN_PROGRESS;

  // Transmit LED data
  const uint8_t* leds = frame->buffer;
  const uint8_t* led_P = led_mapping_P;
  const uint8_t* led_end_P = led_mapping_P + led_count;

  // Start of frame
  write_frame_header();

  while (led_P != led_end_P) {
    // Calculate initial buffer position
    const uint8_t* led_data = leds + sizeof(struct led_t)*pgm_read_byte(led_P++);
    write_byte(LED_HEADER | *led_data);
    // Jump to first, second, and third transmitted component
    led_data += jump_c1;
    write_byte(*led_data);
    led_data += jump_c2;
    write_byte(*led_data);
    led_data += jump_c3;
    write_byte(*led_data);
  }

  // End of frame
  write_frame_footer();

  frame->flags &= ~FRAME_DRAW_IN_PROGRESS;
}


void display_blank() {
  // Start of frame
  write_frame_header();

  // LED data
  for (uint8_t i = 0; i < led_count; ++i) {
    write_byte(LED_HEADER);
    write_byte(0);
    write_byte(0);
    write_byte(0);
  }

  // End of frame
  write_frame_footer();
}

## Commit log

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2015-12-12 Change order of register configuration to ensure correct SPI operation.
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2015-12-13 Add technical drawing of display housing.
    [pocket_icetop.dxf]
2015-12-14 Pointer to frame buffer improvements.
    Don't allocate frame buffer as 2D array, but 1D array for easier use
    of pointers.
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2015-12-15 Fix frame buffer filling UART state, off-by-one bug.
2015-12-15 Fix description of frame size, infill stations are not available (stations 79-81).
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2015-12-16 Refactor frame buffer code.
    Still implemented as a double buffer, but now using an array RGB structs.
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2015-12-17 Fix display driving loop.
    [display_driver.c]
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2015-12-17 Update frames receiving USART state to fill track frame filling.
    This replaces the second FSM that was used before to keep track of when a full frame was ready,
    but mainly consisted of duplicated code.
2015-12-17 Fix order of RGB components in led_t struct.
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2015-12-20 Add holes in baseplate for cables.
    [pocket_icetop.dxf]
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2015-12-27 Copy the Arduino USART configuration to have a fully functional serial port.
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2016-01-05 Update baseplate drawing.
    [pocket_icetop.dxf]
2016-01-05 Clear and (re)enable interrupts when setting USART data register empty interrupt enable.
2016-01-07 Track missing file with support for rendering to a terminal.
    [textdisplay.py]
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2016-01-13 Add missing numpy import.
    [led_format.py]
2016-01-14 Return correct (new) frame format for overview frames.
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2016-01-25 Redo baseplate drawing with correct strip dimensions.
    [pocket_icetop.dxf]
2016-02-02 Minor changes to base plate drawing (layers).
    [pocket_icetop.dxf]
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2016-02-14 Replace front and back buffers by a more flexible system of a frame queue.
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2016-02-14 Write remote frame data to new buffer and push on transfer completion.
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2016-02-18 Fix memory leak/stack collision: mark frames to be freed after drawing.
2016-02-18 Configure both switches and use the correct register for reading the pin value.
    [switches.c]
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2016-02-19 Refactor and fixes in switches module.
    * Use correct register to enable debouncing timer.
    * Fix assignment bug when reading switch_pressed value.
    * Make switch_pressed definition private.
    [switches.c]
2016-02-19 Start device in idle mode.
    Device starts with cleared display and will transistion to demo
    mode when pressing any of the user buttons.
2016-03-19 USB configuration management.
    [configuration.h]
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2016-03-25 Set correct device state after configuration.
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2016-03-30 Provide correct USB device information.
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2016-04-01 New USB communication mode. Only descriptor transfer is moved to a fully interrupt based method, others still use the previous implementation.
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2016-04-05 Be more carefull when allocating and pushing frames into the queue. Checking for failed/impossible pushes prevents possible memory leaks.
2016-04-05 Fix bug where empty frame was pushed instead of a rendered frame. (copy pasta...)
2016-04-08 Add support for WS2811 LEDs and make compatible led_format.py compatible with python 2.7
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2016-04-12 Add support for finite duration displayed pulses and fix LED brightness compression.
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2016-04-13 Fix bug with short finite pulses where the actual LED on-time was too long. Explicitly reset brightness and split color map into a list of groups of overlapping pulse.
2016-04-13 Add error when trying to include unsupported switches on Arduino.
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2016-04-15 Change unused bits to values read by programming device to prevent verification errors.
2016-04-15 Move upload_eeprom target to UGent-controller-only area and add target to upload all device images at once.
2016-04-15 Track KiCad PCB design of display controller.
    [pocket-icetop.kicad_pcb, pocket-icetop.sch]
2016-05-09 Actually accumulated displayed charge instead of multiplying the first charge with the number of shown pulses.
2016-05-12 Be more forgiving on null-pointers for renderer functions and move rendering timer initialisation.
2016-05-13 Add pull-down on LED_CLK to schematic.
    [pocket-icetop.sch]
2016-05-13 Drop DFU jumper by using SW3 as dual-purpose input: demo button and DFU select during reset.
    [pocket-icetop.kicad_pcb, pocket-icetop.sch]
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2016-05-17 If frame queue is full, let queue destroy the frame to make memory leaks less likely.
2016-05-20 Signal switch press on up-going edge instead of down-going edge. This prevents the display from acting on a button press intented to reset the device for a firmware upgrade.
    [switches.c]
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2016-05-26 Don't push empty frame if there is a renderer without start function.
2016-05-27 Split single frame buffer definitions from frame queue. Make push_frame and pop_frame re-entrant by making the critical part atomic. Remove volatile specifier from variables that shouldn't be volatil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
2016-05-27 Add display blank method that doesn't require a frame buffer.
    [display_driver.c]
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2016-05-30 Use array of statically allocated display frames instead of malloc.
    Using a single, continuous array of display frame buffers prevents
    fragmentation of the heap into large unused areas when combined
    with the use of malloc for the USB communication.
    Pre-allocating also gives more control over exhaustion of memory
    and prevents device malfunction (heap/stack collision) by denying
    buffer allocation.
2016-05-30 Only push non-null frames into frame queue and mark clearing frame as free-able.
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2016-05-31 Remove unused includes.
    [configuration.h]
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2016-06-02 Document the last .h files and some various other small corrections.
    [configuration.h]
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2016-06-03 Minor: more documentation tweaks and corrections.
    [configuration.h]
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2016-06-27 30 LED/m strip housing design with in-fill stations.
    [pocket_icetop_large.dxf]
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2016-06-30 Add LED layout for 81-station display.
    [pocket_icetop_large.dxf]
2016-07-01 Add electrical connections to large display drawing.
    [pocket_icetop_large.dxf]
2016-07-04 Only store device specific display properties in EEPROM.
    The LED count is now the only variable that is not part of the firmware
    itself, since all other properties will be common to all displays.
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2016-07-08 Optimize LED data loop.
    Change incrementing index to incrementing pointer, since the index
    was only used to calculate the pointer offset.
    Change LED component pointer offset to differential offsets to
    save a few cycles and registers by not storing the original pointer.
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2016-08-26 Split off frame draw timer into separate module to make the main loop more portable.
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2016-09-16 Split code into MCU generic parts and application specific display driver.
    FTM and DMA modules provide access to the MCU's timer and DMA module.
    Some register values were changed to provide proper initalisation.
    The LED data buffer constants were redefined and the copy_buffer function
    was updated to function correctly.
    [display_driver.c]
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2016-09-17 Split USB communication module into EP0 logic and more device specific interrupt handling.
2016-09-19 Add 50µs delay timer to ensure proper reset of display LEDs.
    [display_driver.c]
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2016-09-24 Updated large display drawing.
    [pocket_icetop_large.dxf]
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2016-09-25 Don't run in interrupt-less mode. Interrupts should only be enabled once properly configured anyway.
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2016-10-03 Extract/insert the 10-bit byte count using a 10 bit mask, not a 6 bit mask.
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2016-10-03 Stall endpoint if setup could not be processed.
    Stall is automatically cleared upon receival of a new SETUP token.
2016-10-04 Add support for a port count per segment number to possibly shorten buffer copy times and use FRAME_DRAW_IN_PROGRESS to indicate a buffer is being read.
    [display_driver.c]
2016-10-04 Reverse port reading order to make port 0 data end up at the LSB instead of the MSB of the transpose matrix.
    [display_driver.c]
2016-10-05 Reverse port order in matrix instead of buffer pointer array. This way, the first element in the pointer array can still refer to the longest LED strip.
    [display_driver.c]
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2016-10-07 Use unsafe mode to prevent reading of fuses when this is not necessary. Prevents avrdude from complaining when using the flip1 programmer.
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2016-10-07 Allow segmented transmission of display frames to work around size limit of 4096 bytes for control transfers.
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2016-10-08 Support for IceCube display devices, beter USB error handling, and more debug logging.
2016-10-11 Calculate correct buffer offsets for BRG color order.
    [display_driver.c]
2016-10-11 Place memory for LED display DMA transfers in low SRAM and keep all other data in high SRAM so a display write can always run non-interrupted.
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2016-10-14 Use a common usb/endpoint.h header file for AVR and ARM architectures.
    The AVR specific endpoint stack was split off and a platform independent
    endpoint config struct is now used.
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2016-10-20 Support for frame timer counter correction.
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2016-10-21 Add frame draw timer reset USB request.
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2016-10-28 Properly reset an endpoint when reconfiguring or clearing STALL.
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2016-11-04 Initial code for perfoming a frame draw clock phase slip.
2016-11-07 Put common SOF tracking and phase correction code in frame_timer_sof_tracker module.
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2016-11-10 Correct calculation of LED count for DeepCore capable displays.
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2016-11-17 Vendor request to query frame draw timing.
    Since the interrupt endpoint behaves as FIFO, it has to be drained
    at least once to get recent frame draw timing information. With a
    control transfer the information can be latched when the setup
    request is received, ensuring recent information is always available.
    This also doesn't require to wait for the next transfer opportunity
    of the interrupt endpoint, which is annoying when you only have blocking
    call available in Python.
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2016-12-01 Actual working multithreading code.
    The worker threads are started when a display is selected by an
    LedDisplay artist and stopped the display is no longer needed.
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2016-12-06 First batch of file moves to new source tree
    [configuration.h]
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2016-12-23 Track missing rain renderer implementation.
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2017-01-05 Big batch of documentation changes.
    [configuration.h]
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2017-01-11 Improve documentation of C headers, mainly improving grouping of functionality.
    [configuration.h]
2017-01-11 Various small improvements to the documentation.
    [configuration.h]
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2017-01-12 Move pocket-icetop hardware files to new location.
    [pocket-icetop.kicad_pcb, pocket-icetop.sch, pocket_icetop.dxf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]
2017-01-16 Fix path to teensy-loader utility.
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2017-01-19 Reinitialise endpoint after clearing endpoint halt.
    [configuration.h]
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2017-01-24 IceCube display PCB designs.
    [data_connector_pcbs.kicad_pcb, data_connector_pcbs.sch, string_adapter.kicad_pcb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]
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2017-02-06 Move PCB design files to a subdirectory.
    [data_connector_pcbs.kicad_pcb, data_connector_pcbs.sch, string_adapter.kicad_pcb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]
2017-02-06 Strip suspension design files and directory contents description.
    [back_bottom.scad, back_top.scad, clamp_all.scad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]
2017-02-06 Swap device to config mapping
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2017-04-04 Use correct USB suspend interrupt constant on ATmega32U4.
    Swapped the SUSPI and SUSPE flags, which have the same value but
    refer to different registers.
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2017-06-13 Add option to replace existing Teensy EEPROM
2017-06-19 Small bug fixes and improvements to update_eeprom.py
    * Notify user of possibility to overwrite entire EEPROM.
    * Missing parentheses for getting dictionary key list.
    * Misplaced closing parenthesis in string format-and-print.
2017-06-20 Better tracking of LogicalDisplay initialisation.
    When using a compound display and automatically enabled multithreading,
    frame transmission silently fails if LogicalDisplay.open() was not
    called beforehand. An error message is now issued when attempting to
    transmit data without creating the worker threads.
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2017-06-26 Assorted bug fixes for test_draw.py
    * When using a frame offset, default to a frame range length of 1 instead of stopping at 1.
    * Use the display-provided LED index to find back a certain DOM in the frame buffer.
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2017-08-31 Support for reversing strip segment orientation.
    The Münster group has placed the electronics in the upper part
    of the display, effectively reversing the order of all LED strip
    segments. This change adds a new flag to the EEPROM that indicates
    if the first segment is reversed.
    For uninitialised EEPROM, this means it defaults to the behaviour
    like in the original display design, with the electronics in the
    bottom part of the display.
    [display_driver.c, display_properties.h]
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2017-08-31 Small updates to VirtualController.
    * Complete second virtual display.
    * Insert DeepCore string range at front of device property list
    like in the actual firmware.
    * Check if display data buffer has the correct size.
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
